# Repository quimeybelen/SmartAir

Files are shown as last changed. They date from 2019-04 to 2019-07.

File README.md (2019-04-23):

# SmartAir

SmartAir es un aire inverter pequeño y transportable controlado desde una aplicación Android desde tu celular.  
Se tendrá la posibilidad de controlar la temperatura interna, la temperatura externa, entre otras funciones más detalladas a continuación.
  
###### Integrantes:  
  - Bedetti, Nicolas (37.844.342) --> nbedetti@gmail.com  
  - Hoz, Aylen (40.129.336)--> ailu.hoz28@gmail.com  
  - Torres, Quimey (38.891.324) --> quimey.torres@gmail.com  

### Materiales a disposición:
	- 5 leds verdes.
	- 5 leds azules.
	- 5 leds blancos.
	- 5 leds rojos.
	- 1 buzzer.
	- 1 sensor de inclinación.
	- 1 protoboard de 400 puntos.
	- Arduino Uno SMD CH340.
	- 1 cable USB.
	- 50 cables M-M.
	- 5 resistencias de 200k.
	- 5 resistencias de 10k.
	- 5 resistencias de 1k.
	- 1 tira de 40 pines.
	- 2 celdas peltier TEC1-12706.
	- 3 sensores de temperatura TMP36.
	- Modulo bluetooth HC-06 slave.
	- Sensor optico infrarrojo reflectivo.
	- Modulo WIFI Esp8266.
	- Fuente de PC de 12V.
	- 2 coolers (con disipador).
	- Disipadores.
	- Pasta térmica.
	
### Entradas:
- Sensor de temperatura TMP36 (Temperatura interna): Este sensor será utilizado para conocer la temperatura interna del aire inverter.
- Sensor de temperatura TMP36 (Temperatura externa): Este sensor será utilizado para conocer la temperatura del aire que sale por el cooler frontal del aire inverter.
- Sensor de inclinación: Este sensor será utilizado para detectar cuando el aire inverter sea movido de su lugar de manera manual. En este caso se procederá a apagar el aire para proteger sus componentes en caso de movimientos bruscos.
  
### Salidas:
- Cooler frontal: Este cooler será utilizado para impulsar el aire con la temperatura deseada y/o indicada por el usuario.
- Cooler trasero: Este cooler será utilizado para controlar la temperatura interna del aire inverter para evitar un sobrecalentamiento de los componentes.
- Led verde: Este led indicará cuando SmartAir este encendido.
- Led azul: Este led indicará cuando SmartAir este en modo "aire frio".
- Led rojo: Este led indicará cuando SmartAir este en modo "aire cálido".
  
##### Microentregas:
- Microentrega 1:
- [x] Integrantes del grupo y idea del proyecto.
  
- Microentrega 2:
- [x] Materiales.
- [ ] Entradas y salidas del proyecto.
- [ ] Hardware que cumple las funciones del proyecto.
- [ ] Bloques que componen el proyecto.
  
- Microentrega 3:
- [ ] Diagrama funcional.
- [ ] Diagrama físico.
- [ ] Esquema del producto final.
  
- Microentrega 4:
- [ ] Diagrama lógico.
  
- Microentrega 5:
- [ ] Diagrama de software.
- [ ] Circuito de conexión.
  
- Microentrega 6:
- [ ] Secuencia de diseño incremental.
  
- Microentrega 7:
- [ ] Explicación del proyecto.
- [ ] Objetivos (Para qué sirve, que problema rsuelve y como lo resuelve).
- [ ] Utilización (Como se opera, que necesita para funcionar, en qué secuencia cumple el objetivo).
- [ ] Como funciona internamente.
- [ ] Procedimiento (Como logra el objetivo).

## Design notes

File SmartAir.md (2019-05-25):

# SmartAir

SmartAir es un aire inverter pequeño y transportable controlado desde una aplicación Android desde tu celular.  
Se tendrá la posibilidad de controlar la temperatura interna, la temperatura externa, entre otras funciones más detalladas a continuación.
  
###### Integrantes:  
  - Bedetti, Nicolas (37.844.342) --> nbedetti@gmail.com  
  - Hoz, Aylen (40.129.336)--> ailu.hoz28@gmail.com  
  - Torres, Quimey (38.891.324) --> quimey.torres@gmail.com  

### Materiales a disposición:
	- 5 leds verdes.
	- 5 leds azules.
	- 5 leds blancos.
	- 5 leds rojos.
	- 1 buzzer.
	- 1 sensor de inclinación.
	- 1 protoboard de 400 puntos.
	- Arduino Uno SMD CH340.
	- 1 cable USB.
	- 50 cables M-M.
	- 5 resistencias de 200k.
	- 5 resistencias de 10k.
	- 5 resistencias de 1k.
	- 1 tira de 40 pines.
	- 2 celdas peltier TEC1-12706.
	- 3 sensores de temperatura TMP36.
	- Modulo bluetooth HC-06 slave.
	- Sensor optico infrarrojo reflectivo.
	- Modulo WIFI Esp8266.
	- Fuente de PC de 12V.
	- 2 coolers (con disipador).
	- Disipadores.
	- Pasta térmica.
	
### Entradas:
- Sensor de temperatura TMP36 (Temperatura interna): Este sensor será utilizado para conocer la temperatura interna del aire inverter.
- Sensor de temperatura TMP36 (Temperatura externa): Este sensor será utilizado para conocer la temperatura del aire que sale por el cooler frontal del aire inverter.
- Sensor de inclinación: Este sensor será utilizado para detectar cuando el aire inverter sea movido de su lugar de manera manual. En este caso se procederá a apagar el aire para proteger sus componentes en caso de movimientos bruscos.
  
### Salidas:
- Cooler frontal: Este cooler será utilizado para impulsar el aire con la temperatura deseada y/o indicada por el usuario.
- Cooler trasero: Este cooler será utilizado para controlar la temperatura interna del aire inverter para evitar un sobrecalentamiento de los componentes.
- Led verde: Este led indicará cuando SmartAir este encendido.
- Led azul: Este led indicará cuando SmartAir este en modo "aire frio".
- Led rojo: Este led indicará cuando SmartAir este en modo "aire cálido".
- Celdas peltier: Estas se encenderán y apagarán para controlar la temperatura, tambien se cambiará la polaridad para entregar frío o calor según el modo en el que funcione el aire.
- Buzzer: Se utiliza para indicar de forma sonora el encendido, apagado, cambio de modo, al subir o bajar la temperatura y velocidad de los coolers, ademas para indicar que el dispositivo se encuentra en modo seguridad.
  
##### Microentregas:
- Microentrega 1:
- [x] Integrantes del grupo y idea del proyecto.
  
- Microentrega 2:
- [x] Materiales.
- [x] Entradas y salidas del proyecto.
- [x] Hardware que cumple las funciones del proyecto.
- [x] Bloques que componen el proyecto.
  
- Microentrega 3:
- [x] Diagrama funcional.
- [x] Diagrama físico.
- [x] Esquema del producto final.
  
- Microentrega 4:
- [x] Diagrama lógico.
  
- Microentrega 5:
- [x] Diagrama de software.
- [ ] Circuito de conexión.
  
- Microentrega 6:
- [x] Secuencia de diseño incremental.
  
- Microentrega 7:
- [x] Explicación del proyecto.
- [x] Objetivos (Para qué sirve, que problema rsuelve y como lo resuelve).
- [x] Utilización (Como se opera, que necesita para funcionar, en qué secuencia cumple el objetivo).
- [ ] Como funciona internamente.
- [ ] Procedimiento (Como logra el objetivo).

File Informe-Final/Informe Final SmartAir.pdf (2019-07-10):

Sistemas Operativos Avanzados - UNLaM

# Informe Final

SmartAir

### Integrantes: Bedetti, Nicolas 37.844.342 nbedetti@gmail.com Hoz, Aylen 40.129.336 ailu.hoz28@gmail.com Torres, Quimey 38.891.324 quimey.torres@gmail.com

Página 1 de 34

## Índice

Página 2 de 34

Página 3 de 34

# Smart Air

### Objetivo

Desarrollar un Sistema embebido (Smart Air) aplicando los conocimientos adquiridos durante el cuatrimestre. SmartAir es un aire inverter pequeño y transportable controlado desde una aplicación Android desde tu celular.

Se tendrá la posibilidad de controlar la temperatura interna, la temperatura externa, entre otras funciones más detalladas a continuación.

### Descripción general del sistema – Manual de Uso

Smart Air es un producto diseñado especialmente para poder ser utilizado en cualquier lugar donde puede enchufarse, es perfecto para refrescarse en un día de verano o para calentarse en un día frío de invierno, gracias a que es un aire inverter. Brinda la posibilidad de prender y apagar el aparato, entre otras funciones, a través de una aplicación Android utilizando Bluetooth.

El sistema embebido (SE) tomará la temperatura exterior de la habitación en la que es colocado y la temperatura interna por donde el aire (cálido o frío) es expulsado. De esta forma al seleccionar en la aplicación el modo elegido, sea frío, calor, ventilación (solo aire sin refrigeración o calor) o automático (24°C). Se encenderán en el modo correcto las placas Peltier que tiene internamente para generar frío, calor o esta apagadas según corresponda.

Además, se podrá elegir desde la aplicación con qué velocidad queremos que el aire sea expulsado en caso de requerir enfriar o calentar la habitación más rápido.

Para un mejor uso es recomendable que la parte trasera del dispositivo donde se elimina el aire se apunte al exterior, al igual que los aires convencionales.

El dispositivo también cuenta con un sensor de inclinación el cual permite, cuando el dispositivo está encendido y es transportado, que este se apague para no generar daños internos.

Por último, cuenta con un buzzer que indica cuando el dispositivo se enciende, apaga, cambia de temperatura, velocidad y modo, además de tres leds frontales que indican el estado del dispositivo:

- Al encender el dispositivo se prenderá el led verde.
- Al estar en “modo frío”, además de mantener el led verde de encendido, se prenderá el led azul.
- Al estar en “modo calor”, además de mantener el led verde de encendido, se prenderá el led rojo.

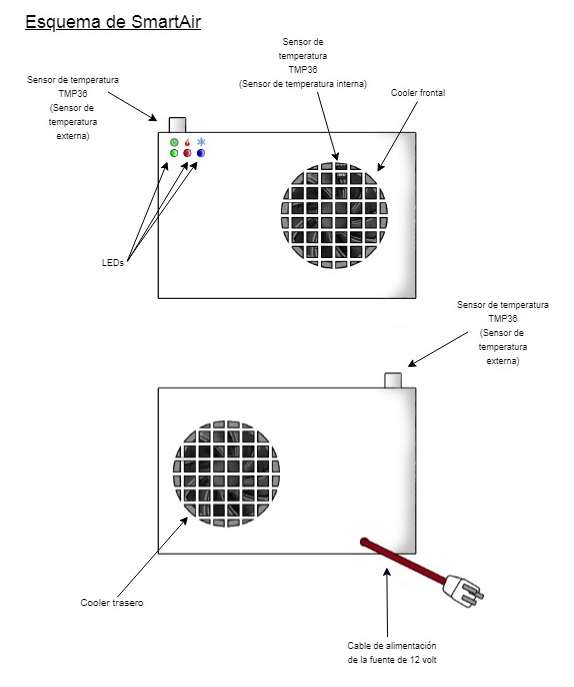
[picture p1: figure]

Página 4 de 34

- Al estar en “modo automático”, además de mantener el led verde de encendido, se prenderán los led azul y rojo.
- Al estar en “modo ventilación”, solo se encuentra encendido el led verde, con solo los ventiladores encendido, sin las peltier.
- Por último, el dispositivo cuando con un “modo seguro”, este se activa cuando el sensor de inclinación detecta que el dispositivo se encuentra en una posición que compromete su integridad, cuando esto sucede se apagarán los led azul y rojo (según corresponda), el buzzer producirá un pitido constante y se apagarán las placas Peltier al igual que los ventiladores internos.

En la siguiente imagen se puede apreciar el dispositivo y como debe ser conectado:

Página 5 de 34

### Componentes

Hardware:
- 1 Placa Arduino UNO SMD CH340.
- 1 Cable USB
- Protoboard de 400 puntos.
- 1 Fuente de computadora 12v.
- Cables macho-macho.
- Cables macho-hembra.
- Pines.
- Modulo Bluetooth HC-05.
- Resistencias 4k7.
- Resistencias 33K.
- Transistores BC337.
- 2 Transistores IRF 540.
- 2 Transistores BC558.
- 2 Transistores BC548.
- Sensores
o 1 Sensor de temperatura TMP-36. o 1 Sensor de temperatura LM-35 o 1 Sensor de inclinación.
- Actuadores
o 1 Buzzer.
o 1 Led Verde.
o 1 Led Rojo.
o 1 Led Azul.
o 2 Celdas Peltier TEC1-12706.
o 2 Coolers con disipador de 8x8cm.

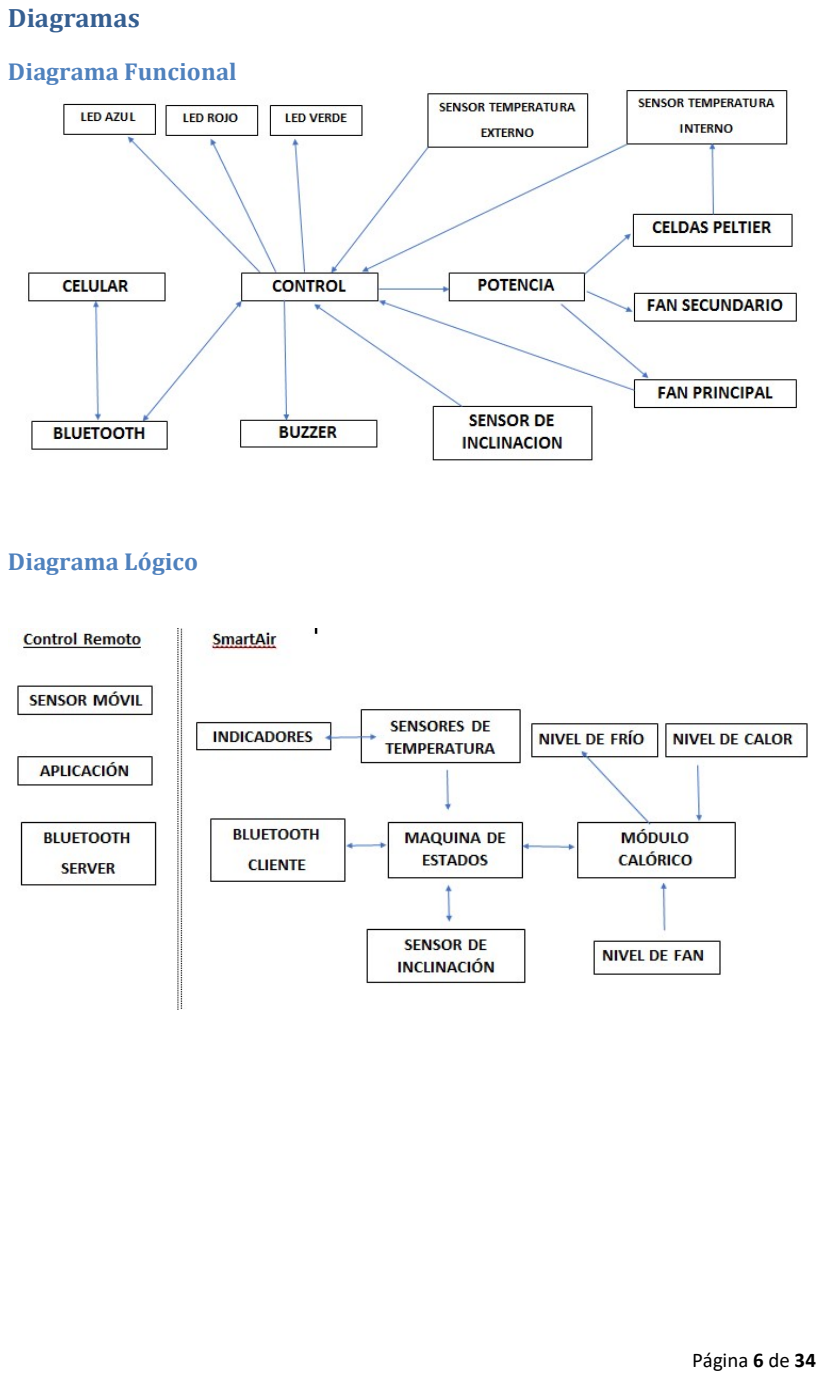
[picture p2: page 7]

Página 6 de 34

### Diagramas

Diagrama Funcional

Diagrama Lógico

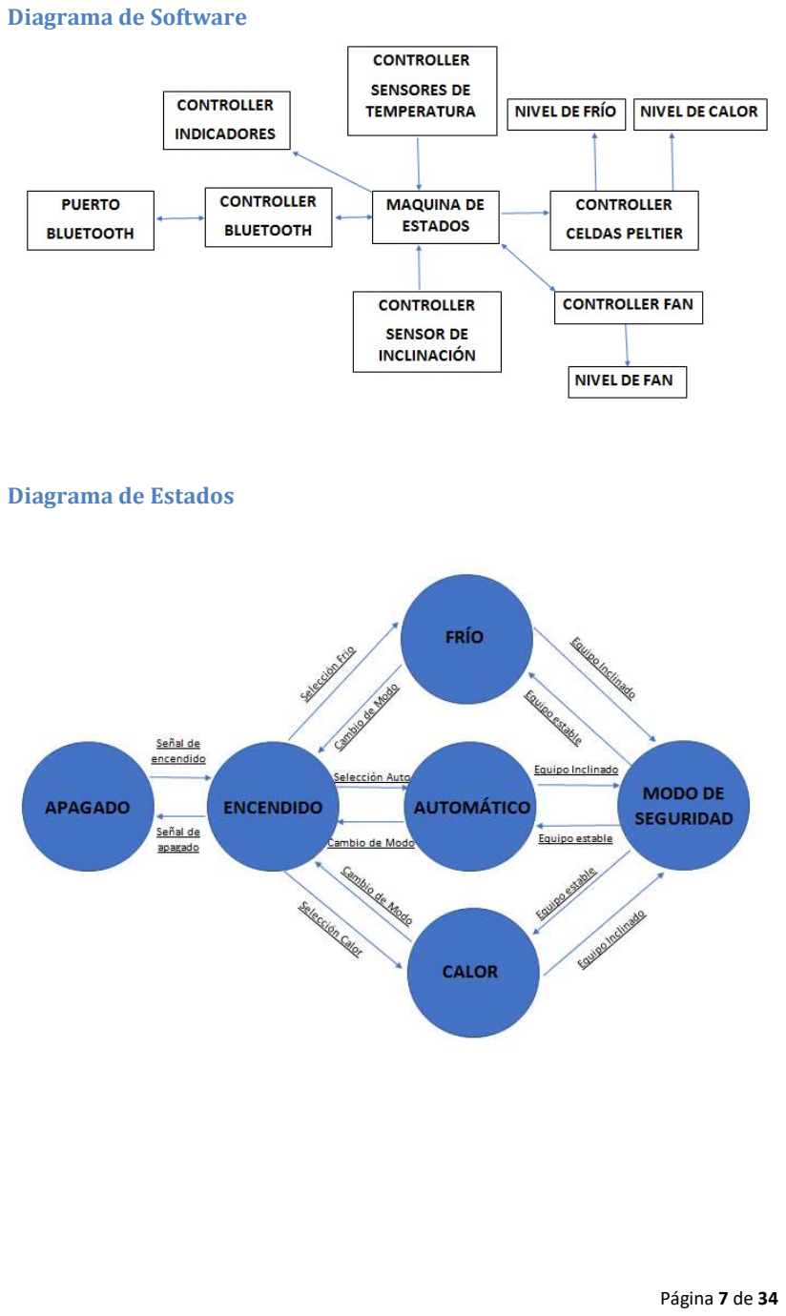
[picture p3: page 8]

Página 7 de 34

Diagrama de Software

Diagrama de Estados

Página 8 de 34

### Implementación del Embebido

Implementación Leds
Pin 4: Led verde (encendido)

Pin 12: Led Azul (modo frío)

Pin 13: Led Rojo (modo calor)

Implementación de Sensor de inclinación
Pin 2: Sensor de inclinación o tilt switch

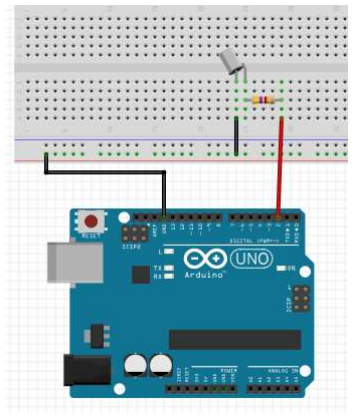
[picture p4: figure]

Página 9 de 34

Implementación de Buzzer
Pin 3 (PWM): Buzzer (se conectó directo)

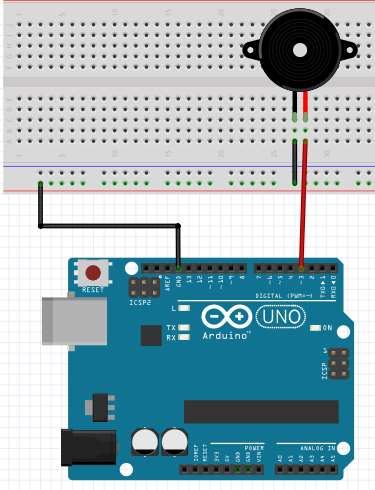
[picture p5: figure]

Implementación de sensores de temperatura
Pin Analógico 0: Sensor de temperatura TMP36 (temperatura interna)

Pin Analógico 1: Sensor de temperatura LM35 (temperatura externa)

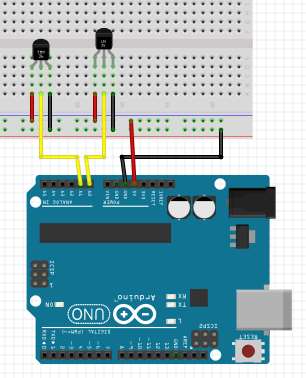
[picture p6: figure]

Página 10 de 34

Implementación de Cooler Frontal
Pin 5 (PWM): control de velocidad del cooler conectando cable de alimentación del cooler a transistor BC337.

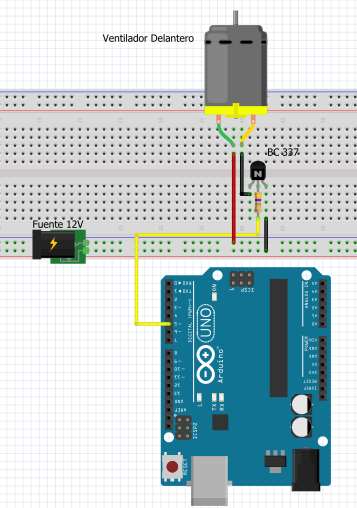
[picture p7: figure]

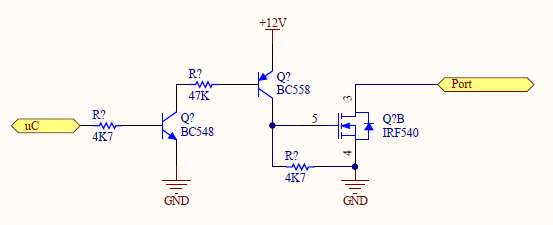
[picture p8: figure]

Página 11 de 34

Implementación de Celdas Peltier:
Las celdas se conectarán cumpliendo con el siguiente circuito, repitiéndolo para cada una:

Pin 6: Peltier para calor.

Pin 7: Peltier para frio.

Implementación módulo Bluetooth HC-05

5V: Vcc

Pin 10 (PWM): TXD

Pin 11 (PWM): RXD

GND: GND

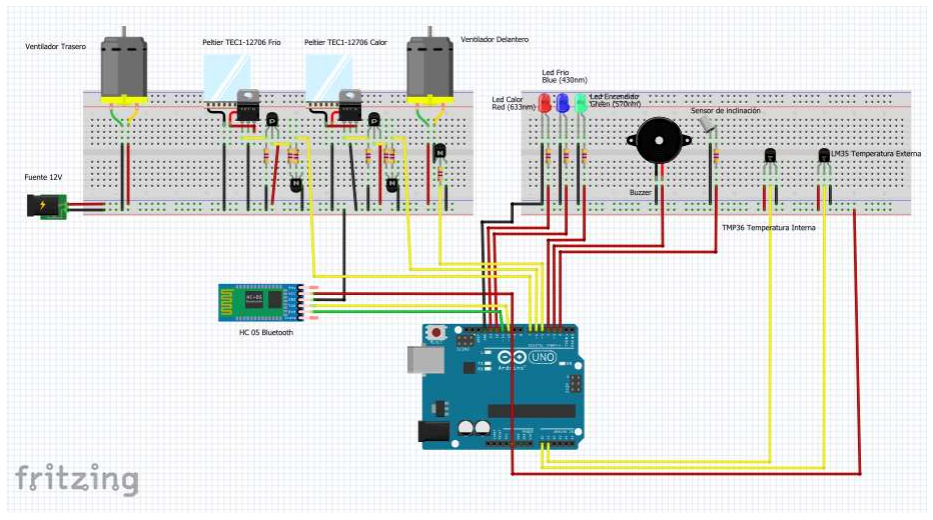
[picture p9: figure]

Página 12 de 34

### Circuito Completo

Como se puede apreciar en la figura, se decidió utilizar dos placas una para los componentes que va a estar mas a la vista como los leds, buzzer y sensores que son componentes delicados y pequeños. Y otra, para los componentes internos y más pesados como el ventilador frontal y las placas peltier. Decidimos no manejar el ventilador trasero y que se encuentra prendido constantemente desde que se conecta el dispositivo debido a que es necesario expulsar el aire desde adentro del dispositivo en todo momento.

Página 13 de 34

### Descripción de los componentes

Arduino Uno:

Arduino es una plataforma de prototipos electrónica de código abierto (open-source) basada en hardware y software flexibles y fáciles de usar. Arduino puede sentir el entorno mediante la recepción de entradas desde una variedad de sensores y puede afectar a su alrededor mediante el control de luces, motores y otros artefactos. El microcontrolador de la placa se programa usando el Arduino Programming Language (basado en Wiring).

La mayor parte de los Arduinos funcionan a 5V, como es el caso del Arduino Uno. Todos tienen un regulador de tensión, que básicamente es un componente que convierte el voltaje que con el que alimentamos la placa (lo recomendado es entre 7 y 12V) a 5V, desechando lo restante.

Este regulador necesita un voltaje mínimo para para proporcionar 5V que está entorno 6.5-7V, pero todo lo que esté por encima de ese valor se desperdicia.

Página 14 de 34

Módulo Bluetooth HC-05

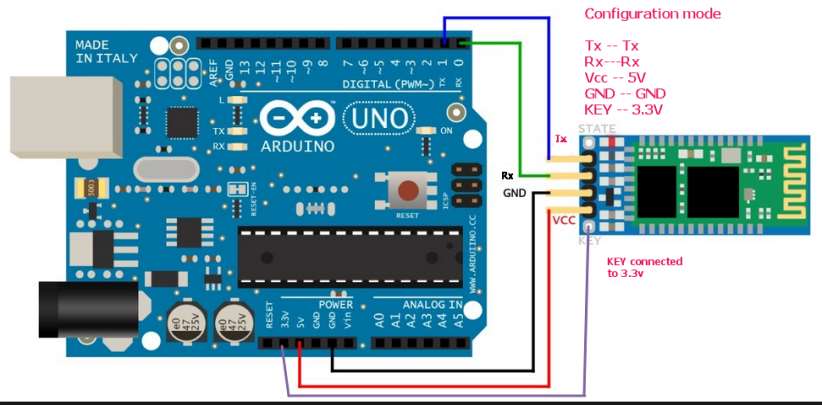
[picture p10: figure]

Estos módulos vienen maestro y esclavo en una misma placa y vía comandos AT se configura cuál de los dos modos queremos usar. Por defecto viene en modo Esclavo.

El chip en si trabaja en 3.3 V, pero viene soldado sobre una placa que adapta todos sus pines para poder usarlo en 5V y así sea 100% compatible con Arduino.

La velocidad por defecto es de 9600 baudios.

Tiene un alcance de 18 metros.

Modulo bluetooth hc-05 como esclavo: Cuando está configurado de esta forma, se comporta similar a un HC-06, espera que un dispositivo bluetooth maestro se conecte a este, generalmente se utiliza cuando se necesita comunicarse con una PC o Celular, pues estos se comportan como dispositivos maestros.

Modulo bluetooth hc-05 como Maestro: En este modo, EL HC-05 es el que inicia la conexión. Un dispositivo maestro solo se puede conectarse con un dispositivo esclavo. Generalmente se utiliza este modo para comunicarse entre módulos bluetooth. Es necesario antes especificar con qué dispositivo se tiene que comunicar. Mediante el pin TX, Arduino enviará datos, y mediante el RX, recibirá datos.

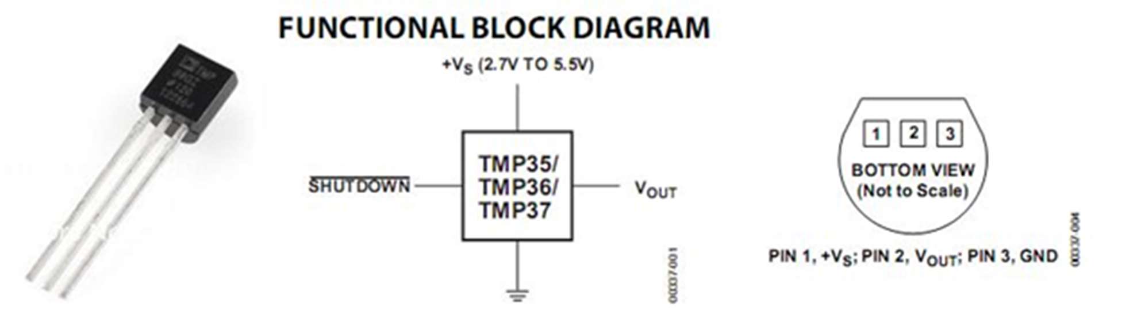
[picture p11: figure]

Página 15 de 34

Sensor de Temperatura TMP-36
El sensor de temperatura TMP36 es un sensor analógico que permite realizar medidas de temperatura bastante precisas.

El sensor empleado es de tipo TO-92 (encapsulado como el DS18B20 o el de algunos transistores). Además, se caracteriza por ser un sensor que es muy empleado para realizar medidas de temperatura y es muy sencillo de emplear (no hacen falta librerías para su uso). Es un sensor que se puede alimentar entre un rango de voltaje que va desde los 2.7V hasta los 5.5V, viene calibrado directamente en grados centígrados (ºC), presenta un factor de escala lineal de 10 mV/ºC (esto es la relación entre el cambio en la señal de salida y el cambio en la señal de la medida, es decir, cada 10 mV aumenta 1 ºC). Las características generales son:

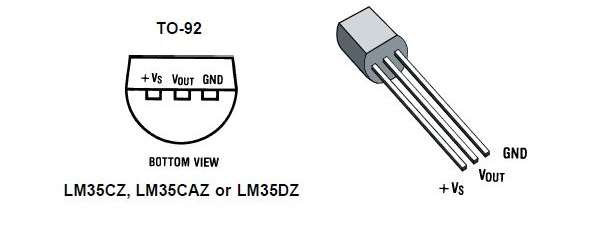
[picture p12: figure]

Página 16 de 34

Sensor de temperatura LM-35

El LM35 es un sensor de temperatura con una precisión calibrada de 1 °C. Su rango de medición abarca desde -55 °C hasta 150 °C. La salida es lineal y cada grado Celsius equivale a

### 10 mV, por lo tanto:

- 150 °C = 1500 mV
- -55 °C = -550 mV1
- Opera de 4v a 30v.
- Está calibrado directamente en grados Celsius.
- La tensión de salida es proporcional a la temperatura.
- Tiene una precisión garantizada de 0.5 °C a 25 °C.
- Baja impedancia de salida.
- Baja corriente de alimentación (60 μA).

El LM35 no requiere de circuitos adicionales para calibrarlo externamente. La baja impedancia de salida, su salida lineal y su precisa calibración hace posible que este integrado sea instalado fácilmente en un circuito de control. Debido a su baja corriente de alimentación se produce un efecto de auto calentamiento muy reducido. Se encuentra en diferentes tipos de encapsulado, el más común es el TO-92, utilizado por transistores de baja potencia.

El TO-92 es el encapsulado más utilizado en la construcción de transistores. El encapsulado está usualmente hecho de epoxy o plástico, y presenta un tamaño bien

Página 17 de 34

Sensor de Inclinación

Son sensores de unos pocos milímetros de longitud, que llevan en su interior una o dos pequeñas bolas conductoras, capaces de cerrar el circuito con los pines metálicos inferiores del cilindro.

Cuando hacen contacto permiten el paso de la corriente y

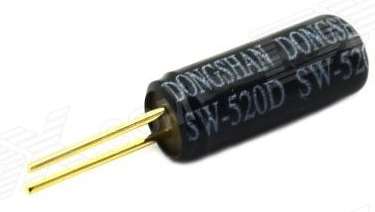
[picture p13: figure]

cierran el contacto exactamente igual que si fueran un interruptor (Y de hecho se manejan igual) pero que a partir de un cierto Angulo de inclinación dejan de hacer contacto y abren el contacto.

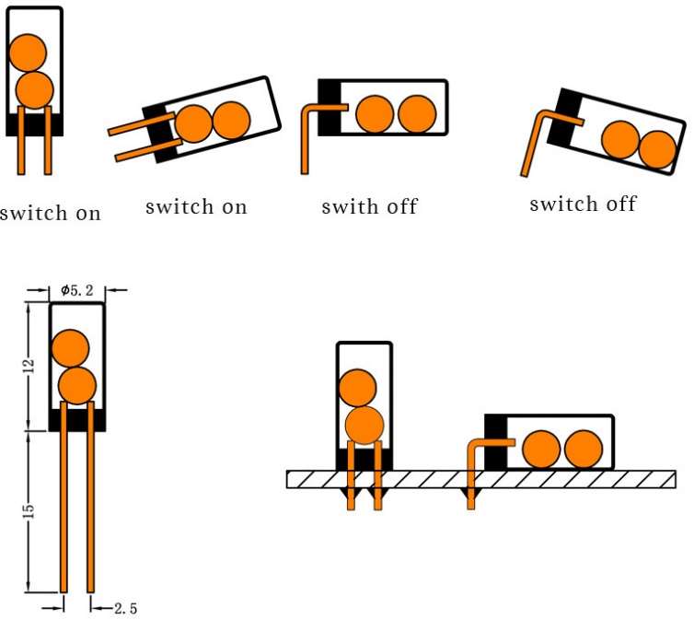
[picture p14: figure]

LED
Un diodo emisor de luz o led (light-emitting diode) es una fuente de luz constituida por un material semiconductor dotado de dos terminales. Se trata de un diodo de unión p-n, que emite luz cuando está activado. Si se aplica una tensión adecuada a los terminales, los electrones se recombinan con los huecos en la región de la unión p-n del dispositivo, liberando energía en forma de fotones. Este efecto se denomina electroluminiscencia, y el color de la luz generada (que depende de la energía de los fotones emitidos) viene determinado por la anchura de la banda prohibida del semiconductor. Los ledes son normalmente

pequeños (menos de 1 mm) y se les asocian algunas componentes ópticas para configurar un patrón de radiación.

Página 18 de 34

Buzzer

Es un transductor electroacústico que produce un sonido o zumbido continuo o intermitente de un mismo tono (generalmente agudo). Sirve como mecanismo de señalización o aviso y se utiliza en múltiples sistemas, como en automóviles o en electrodomésticos, incluidos los despertadores.

Inicialmente este dispositivo estaba basado en un sistema

electromecánico que era similar a una campana eléctrica, pero sin el badajo metálico, el cual imitaba el sonido de una campana.

Su construcción consta de dos elementos, un electroimán o disco piezoeléctrico y una lámina metálica de acero. El buzzer puede ser conectado a circuitos integrados especiales para así lograr distintos tonos.

Cuando se acciona, la corriente pasa por la bobina del electroimán y produce un campo magnético variable que hace vibrar la lámina de acero sobre la armadura, o bien, la corriente pasa por el disco piezoeléctrico haciéndolo entrar en resonancia eléctrica y produciendo ultrasonidos que son amplificados por la lámina de acero.
Celda Peltier TEC1-12706
Especificaciones:
- Material cerámico
- Cable de 30cm
- Temperatura lado caliente: 50-57ºC
- Delta de temperatura: 66-75ºC
- Corriente máxima: 6.4A
- Voltaje nominal: 12V
- Voltaje máximo: 16.4V
- Potencia nominal: 72W
- Resistencia de la celda 1.98-2.30 Ohms

Se utiliza para enfriar o calentar un objeto, ideal para experimentos o controles de temperatura, si se utiliza por largos periodos de tiempo se recomienda utilizar un disipador en la zona caliente, además de recubrir la zona con pasta termina para una mejor termo conducción de los materiales. La celda se controla con 12V, pero puedes utilizarla con un rango de voltaje de los 3 a los 16V. Dado que la celda consume una cantidad considerable de corriente tienes que tomar en cuenta que tu fuente tenga la corriente necesaria, si no, no va a funcionar con su máxima eficiencia.

Una celda peltier contiene un arreglo de paletas de semiconductor de material Bismuto Telurio que se encuentran dopadas con un tipo de portador positivo o negativo. Los pares de portadores se configuran para estar conectados en serie eléctricamente y en paralelo

Página 19 de 34

térmicamente hablando. Cuando un voltaje de corriente directa se aplica al módulo, las cargas positivas y negativas de los portadores absorben energía de un sustrato y la transfiere al sustrato del lado opuesto. La superficie que absorbe la energía caliente se enfría y la superficie donde la energía calorífica se desprende, se calienta. Si se polariza la celda peltier al inverso, el proceso enfría la cara opuesta.

Cuando una celda peltier se polariza, la cara o lado fría absorbe "calor" y la cara que pierde energía emite calor. La diferencia entre ambas caras hará que al final la celda se caliente más de lo que se enfría. Por lo tanto, para montar una celda peltier se requiere tener un disipador. De preferencia este disipador debería de ser de Aluminio el cual es más eficiente para dispersar la temperatura extra. Cuando una celda peltier se encuentra montada a un radiador se tiene una unidad de enfriado.

Página 20 de 34

### Aplicación Android

Composición de la aplicación
La aplicación Android del embebido SmartAir se encuentra compuesta por:
- 11 activities con sus respectivos archivos XML:
- MainActivity: Representa la pantalla de inicio de la aplicación donde puede elegirse el modo en el que se encontrará SmartAir.
- ModoFrioActivity: Representa la pantalla de ‘modo frio’ de la aplicación cuando SmartAir se encuentra en su modo frio.
- ModoCalorActivity: Representa la pantalla de ‘modo calor’ de la aplicación cuando SmartAir se encuentra en su modo ‘calefacción’.
- ModoAutomaticoActivity: Representa la pantalla de ‘modo automático’ de la aplicación cuando SmartAir se encuentra en su modo automático, es decir que la temperatura ideal será elegida por SmartAir, siendo esta de 24 °C.
- ModoVentilacionActivity: Representa la pantalla de ‘modo ventilación’ de la aplicación cuando SmartAir se encuentra en su modo ventilación donde únicamente se encuentra encendido el ventilador.
- ModoSeguroActivity: Representa la pantalla de ‘modo seguro’ de la aplicación cuando SmartAir se encuentra siendo transportado de manera brusca, por lo que sus componentes se encuentran en peligro.
- ErrorConexionMainActivity: Representa el mensaje de error de la aplicación que aparece cuando nos encontramos en la pantalla de inicio y se intenta comunicar con SmartAir, siendo la comunicación rechazada debido a que el mismo no se encuentra conectado.
- ErrorConexionFrioActivity: Representa el mensaje de error de la aplicación que aparece cuando nos encontramos en la pantalla de ‘modo frio’ y se intenta comunicar con SmartAir, siendo la comunicación rechazada debido a que el mismo no se encuentra conectado.
- ErrorConexionCalorActivity: Representa el mensaje de error de la aplicación que aparece cuando nos encontramos en la pantalla de ‘modo calor’ y se intenta comunicar con SmartAir, siendo la comunicación rechazada debido a que el mismo no se encuentra conectado.
- ErrorConexionAutomaticoActivity: Representa el mensaje de error de la aplicación que aparece cuando nos encontramos en la pantalla de ‘modo automático’ y se intenta comunicar con SmartAir, siendo la comunicación rechazada debido a que el mismo no se encuentra conectado.
- ErrorConexionVentilacionActivity: Representa el mensaje de error de la aplicación que aparece cuando nos encontramos en la pantalla de ‘modo ventilación’ y se intenta comunicar con SmartAir, siendo la comunicación rechazada debido a que el mismo no se encuentra conectado.
- 2 servicios:
- ConexionBluetoothService: Nos provee el servicio de comunicación vía bluetooth entre la aplicación de Android y SmartAir, tanto para el envío de mensajes de la aplicación al SmartAir y viceversa.

Página 21 de 34

- SensoresService: Nos provee el servicio de los sensores de proximidad, luz y el shake, detectando los cambios que ocurren en los mismos y realizando, a partir de estos cambios detectados, acciones específicas.
- Sensor de proximidad: Cuando el sensor detecte que el dispositivo móvil se encuentra muy próximo a un objeto y la aplicación se encuentra abierta, bloqueara todos los botones de la pantalla en la cual se encuentre la aplicación.
- Sensor de luz: Cuando el sensor de luz detecte que en el ambiente donde se encuentra el dispositivo móvil tiene una luz muy tenue y no se detectan cambios en el sensor de proximidad, indicara a SmartAir que deberá cambiarse a modo automático. Si el usuario no desea que SmartAir se encuentre en dicho modo, podrá optar por cambiarlo.
- Shake: Cuando el dispositivo móvil detecte un shake, indicara al SmartAir que debe prenderse u apagarse dependiendo en qué modo este al momento de ocurrido el shake.

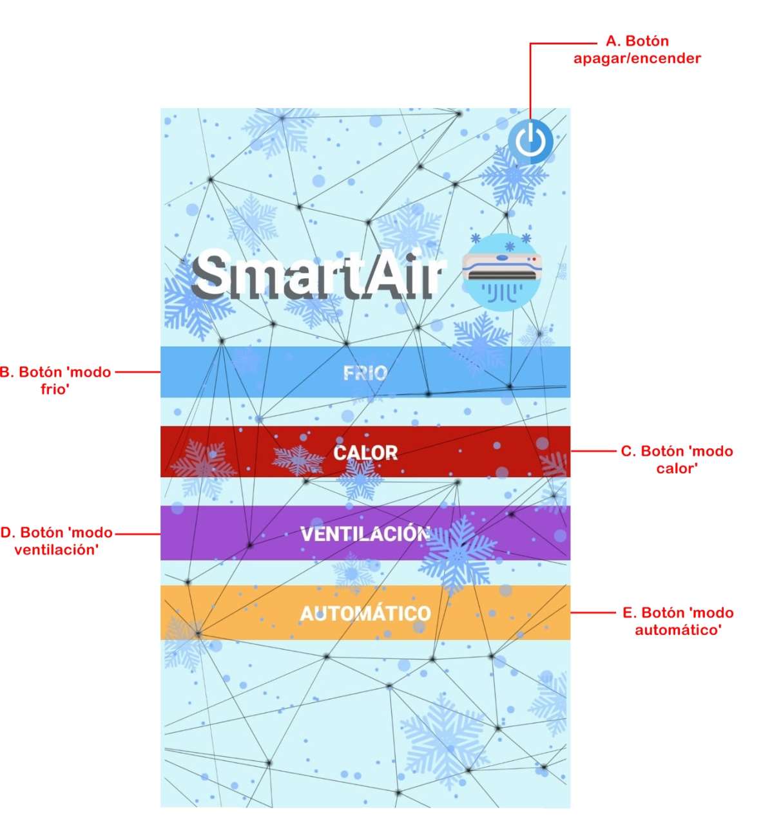
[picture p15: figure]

Página 22 de 34

Pantallas de la aplicación

- MainActivity:
A. Botón apagar/encender: Al presionar dicho botón se encenderá u apagará SmartAir dependiendo el estado en el que el mismo se encontraba cuando el botón fue seleccionado. En caso de que SmartAir se encuentre apagado, la pantalla tendrá sus botones deshabilitado como se observa en la figura.
B. Botón ‘modo frio’: Al seleccionar dicho botón indicaremos a SmartAir que deseamos el modo frio y la aplicación mostrara la pantalla de control del modo correspondiente.
C. Botón ‘modo calor’: Al seleccionar dicho botón indicaremos a SmartAir que deseamos el modo calor y la aplicación mostrara la pantalla de control del modo correspondiente.
D. Botón ‘modo ventilación’: Al seleccionar dicho botón indicaremos a SmartAir que deseamos el modo ventilación y la aplicación mostrara la pantalla de control del modo correspondiente.
E. Botón ‘modo automático’: Al seleccionar dicho botón indicaremos a SmartAir que deseamos el modo automático y la aplicación mostrara la pantalla de control del modo correspondiente.

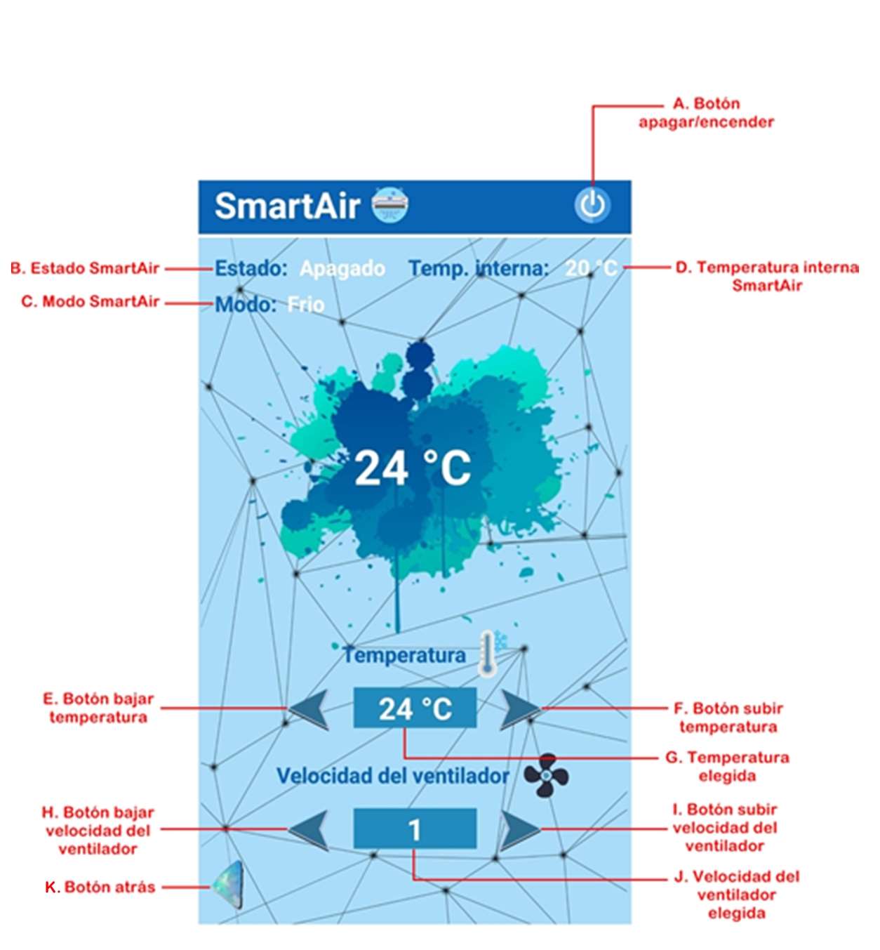
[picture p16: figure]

Página 23 de 34

- ModoFrioActivity:
A. Botón apagar/encender: Al presionar dicho botón se encenderá u apagará SmartAir dependiendo el estado en el que el mismo se encontraba cuando el botón fue seleccionado. En caso de apagar SmartAir, la aplicación volverá a la pantalla de inicio.
B. Estado SmartAir: Nos indica si SmartAir se encuentra prendido u apagado.
C. Modo SmartAir: Nos indica que SmartAir se encuentra en ‘modo frio’.
D. Temperatura interna SmartAir: Nos indica la temperatura que posee internamente SmartAir.
E. Botón bajar temperatura: Al seleccionar dicho botón disminuimos en uno el valor de la temperatura elegida.

Página 24 de 34

F. Botón subir temperatura: Al seleccionar dicho botón aumentamos en uno el valor de la temperatura elegida.
G. Temperatura elegida: Indica la temperatura seleccionada por el usuario de la aplicación. Puede ser modificada con los botones de bajar temperatura y subir temperatura, pero dicho valor nunca podrá ser menor que 18 °C, mayor a 26 °C, ni mayor a la temperatura externa plasmada en la mancha de tinta de la pantalla.
H. Botón bajar velocidad del ventilador: Al seleccionar dicho botón disminuimos en uno el valor de la velocidad del ventilador elegida.
I. Botón subir velocidad del ventilador: Al seleccionar dicho botón aumentamos en uno el valor de la velocidad del ventilador elegida.
J. Velocidad del ventilador elegida: Indica la velocidad del ventilador seleccionada por el usuario de la aplicación. Puede ser modificada con los botones de bajar velocidad del ventilador y subir velocidad del ventilador, pero dicho valor nunca podrá ser menor que 1 ni mayor a 5.
K. Botón atrás: Al seleccionar dicho botón volveremos a la pantalla de inicio, lo cual nos permitirá seleccionar otro modo deseado.

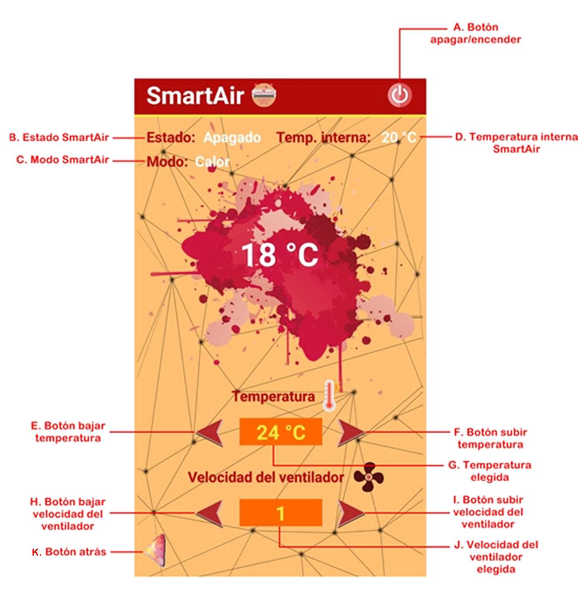
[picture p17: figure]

Página 25 de 34

- ModoCalorActivity:
A. Botón apagar/encender: Al presionar dicho botón se encenderá u apagará SmartAir dependiendo el estado en el que el mismo se encontraba cuando el botón fue seleccionado. En caso de apagar SmartAir, la aplicación volverá a la pantalla de inicio.
B. Estado SmartAir: Nos indica si SmartAir se encuentra prendido u apagado.
C. Modo SmartAir: Nos indica que SmartAir se encuentra en ‘modo calor’.
D. Temperatura interna SmartAir: Nos indica la temperatura que posee internamente SmartAir.
E. Botón bajar temperatura: Al seleccionar dicho botón disminuimos en uno el valor de la temperatura elegida.
F. Botón subir temperatura: Al seleccionar dicho botón aumentamos en uno el valor de la temperatura elegida.
G. Temperatura elegida: Indica la temperatura seleccionada por el usuario de la aplicación. Puede ser modificada con los botones de bajar temperatura y subir temperatura, pero dicho

Página 26 de 34

valor nunca podrá ser menor que 18 °C, mayor a 26 °C, ni menor a la temperatura externa plasmada en la mancha de tinta de la pantalla.

H. Botón bajar velocidad del ventilador: Al seleccionar dicho botón disminuimos en uno el valor de la velocidad del ventilador elegida.
I. Botón subir velocidad del ventilador: Al seleccionar dicho botón aumentamos en uno el valor de la velocidad del ventilador elegida.
J. Velocidad del ventilador elegida: Indica la velocidad del ventilador seleccionada por el usuario de la aplicación. Puede ser modificada con los botones de bajar velocidad del ventilador y subir velocidad del ventilador, pero dicho valor nunca podrá ser menor que 1 ni mayor a 5.
K. Botón atrás: Al seleccionar dicho botón volveremos a la pantalla de inicio, lo cual nos permitirá seleccionar otro modo deseado.

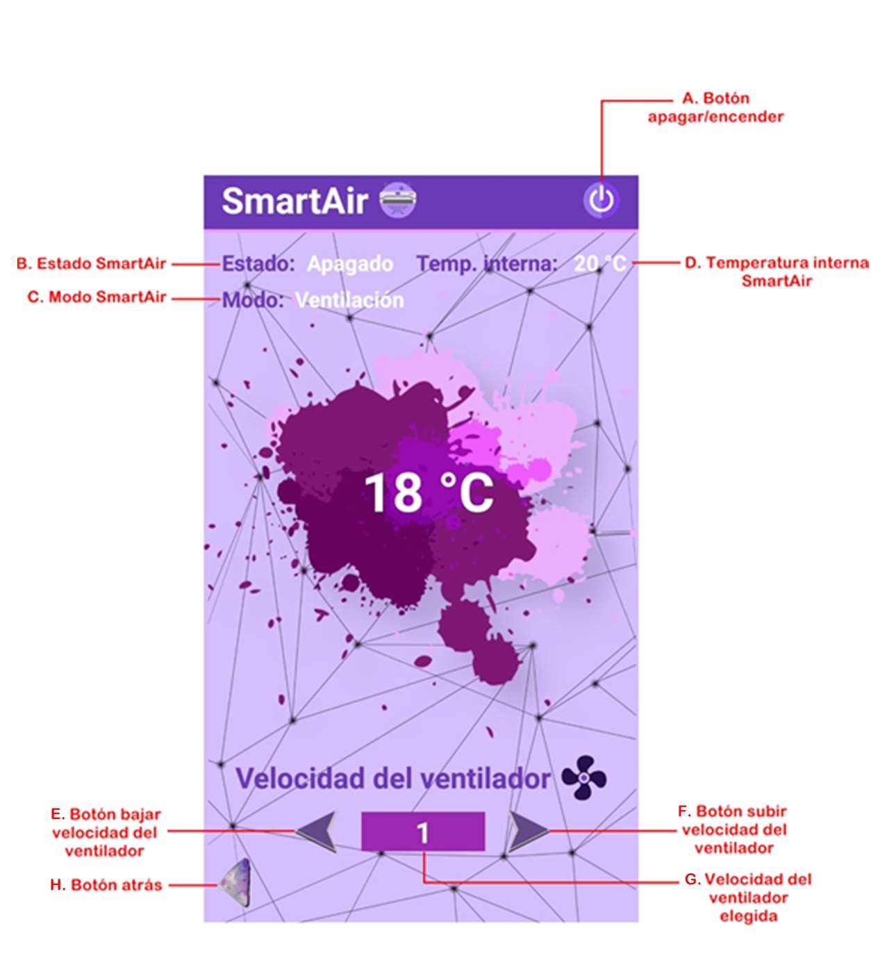
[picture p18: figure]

Página 27 de 34

-ModoVentilacionActivity:

A. Botón apagar/encender: Al presionar dicho botón se encenderá u apagará SmartAir dependiendo el estado en el que el mismo se encontraba cuando el botón fue seleccionado. En caso de apagar SmartAir, la aplicación volverá a la pantalla de inicio.
B. Estado SmartAir: Nos indica si SmartAir se encuentra prendido u apagado.
C. Modo SmartAir: Nos indica que SmartAir se encuentra en ‘modo ventilación’.
D. Temperatura interna SmartAir: Nos indica la temperatura que posee internamente SmartAir.
E. Botón bajar velocidad del ventilador: Al seleccionar dicho botón disminuimos en uno el valor de la velocidad del ventilador elegida.

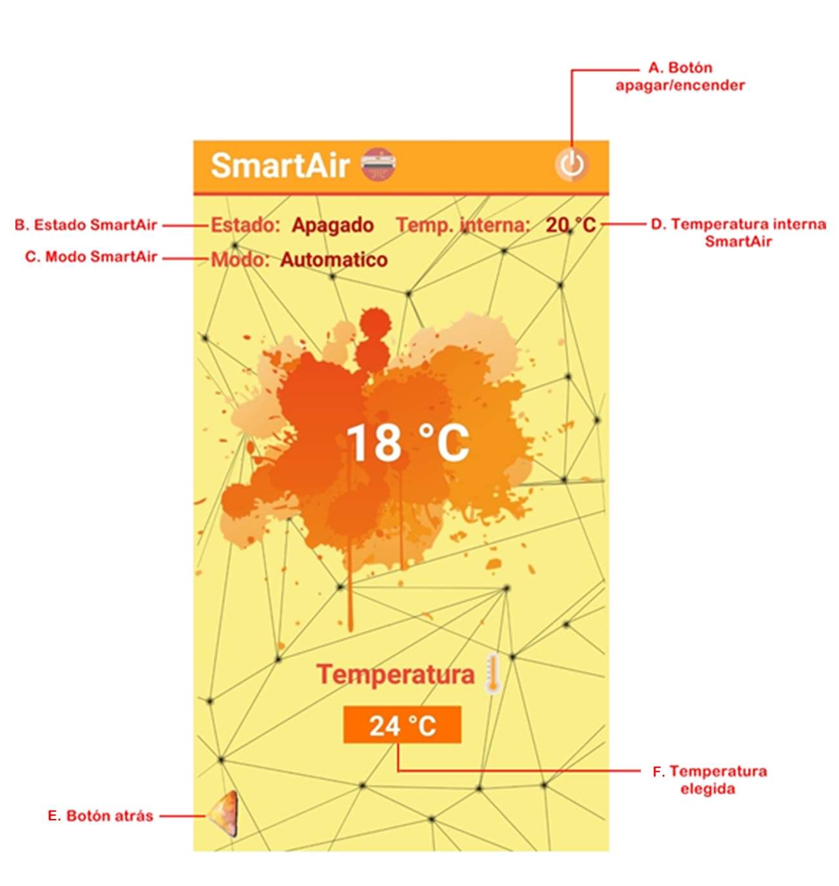
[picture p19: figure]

Página 28 de 34

F. Botón subir velocidad del ventilador: Al seleccionar dicho botón aumentamos en uno el valor de la velocidad del ventilador elegida.
G. Velocidad del ventilador elegida: Indica la velocidad del ventilador seleccionada por el usuario de la aplicación. Puede ser modificada con los botones de bajar velocidad del ventilador y subir velocidad del ventilador, pero dicho valor nunca podrá ser menor que 1 ni mayor a 5.
H. Botón atrás: Al seleccionar dicho botón volveremos a la pantalla de inicio, lo cual nos permitirá seleccionar otro modo deseado.

-ModoAutomaticoActivity:

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

Página 29 de 34

C. Modo SmartAir: Nos indica que SmartAir se encuentra en ‘modo frio’.
D. Temperatura interna SmartAir: Nos indica la temperatura que posee internamente SmartAir.
E. Temperatura elegida: Indica la temperatura seleccionada, la cual en este modo resulta ser siempre de 24 °C.
F. Botón atrás: Al seleccionar dicho botón volveremos a la pantalla de inicio, lo cual nos permitirá seleccionar otro modo deseado.

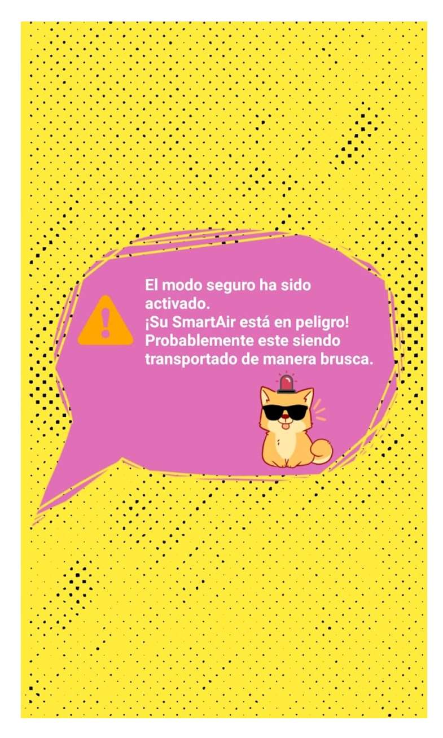
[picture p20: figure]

- ModoSeguroActivity:

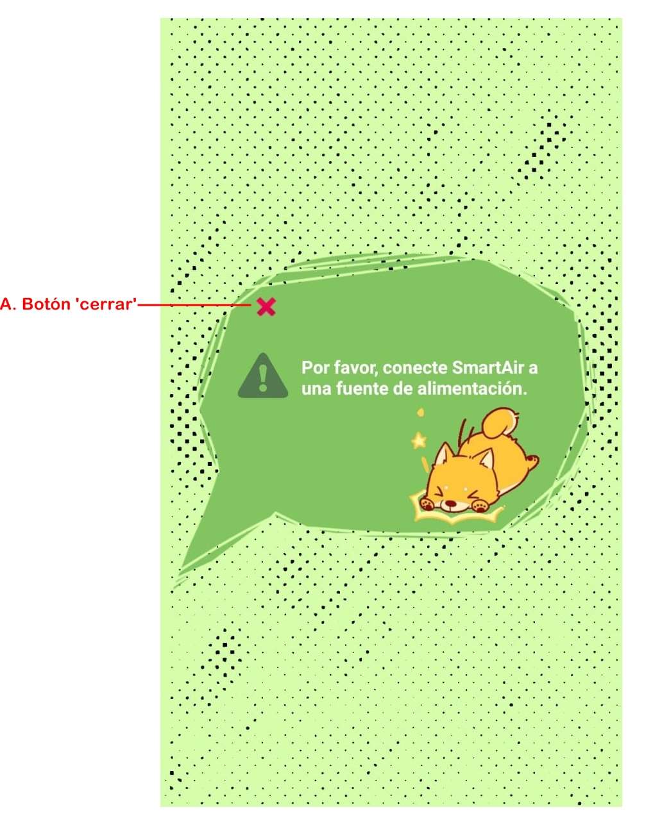
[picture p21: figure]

Página 30 de 34

- ErrorConexionMainActivity:
A. Botón ‘cerrar’: Al seleccionar dicho botón cerraremos el mensaje de error que surge cuando existe una falla de conexión con SmartAir mientras se está en la pantalla de inicio.

Página 31 de 34

- ErrorConexionFrioActivity:
A. Botón ‘cerrar’: Al seleccionar dicho botón cerraremos el mensaje de error que surge cuando existe una falla de conexión con SmartAir mientras se está en ‘modo frio’.

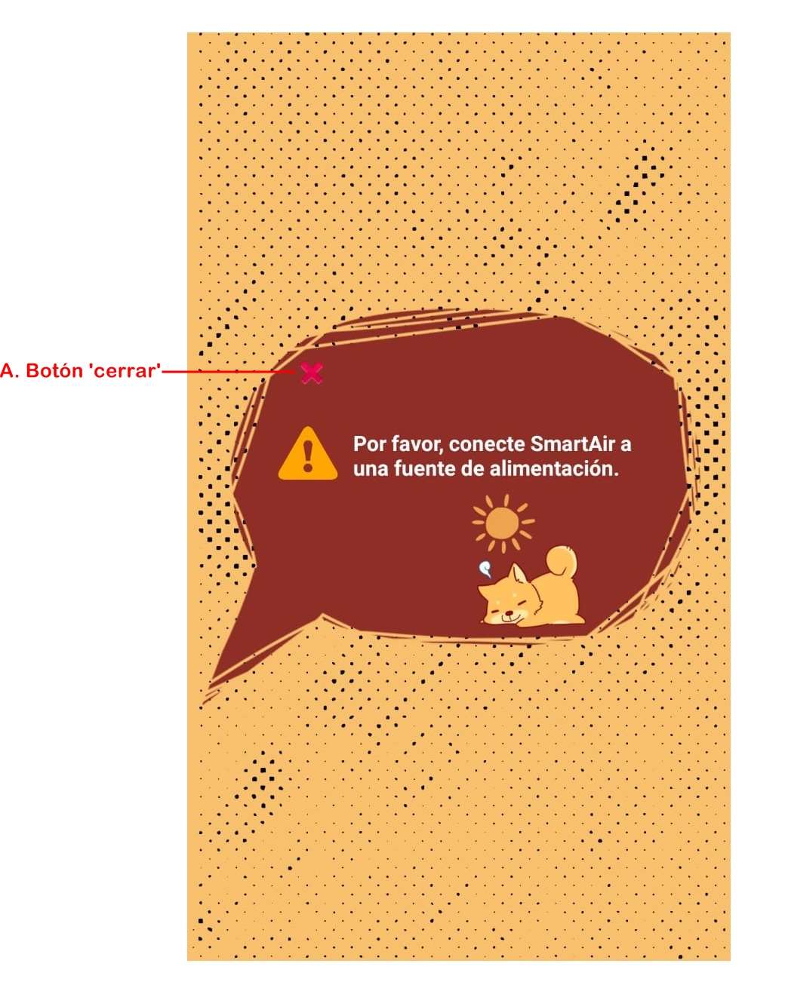
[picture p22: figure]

Página 32 de 34

- ErrorConexionCalorActivity:
A. Botón ‘cerrar’: Al seleccionar dicho botón cerraremos el mensaje de error que surge cuando existe una falla de conexión con SmartAir mientras se está en ‘modo calor’.

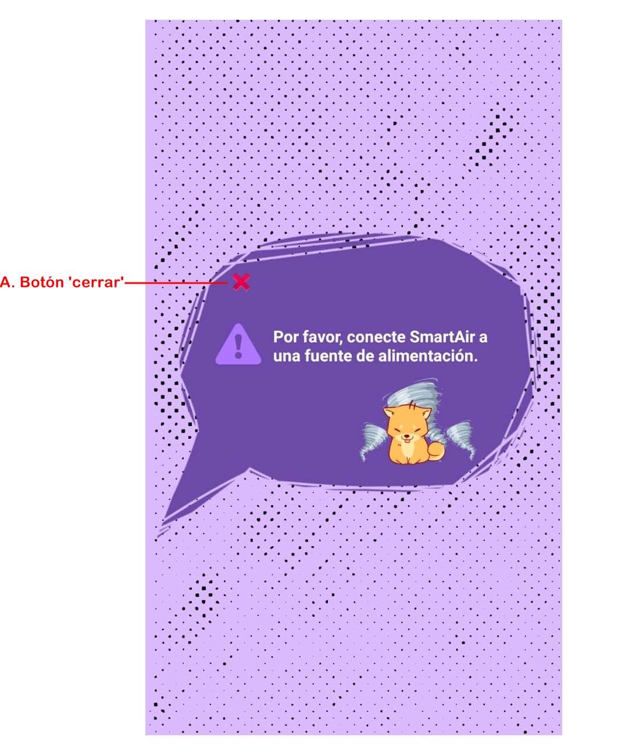
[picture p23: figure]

Página 33 de 34

-ErrorConexionVentilacionActivity:

A. Botón ‘cerrar’: Al seleccionar dicho botón cerraremos el mensaje de error que surge cuando existe una falla de conexión con SmartAir mientras se está en ‘modo ventilación’.

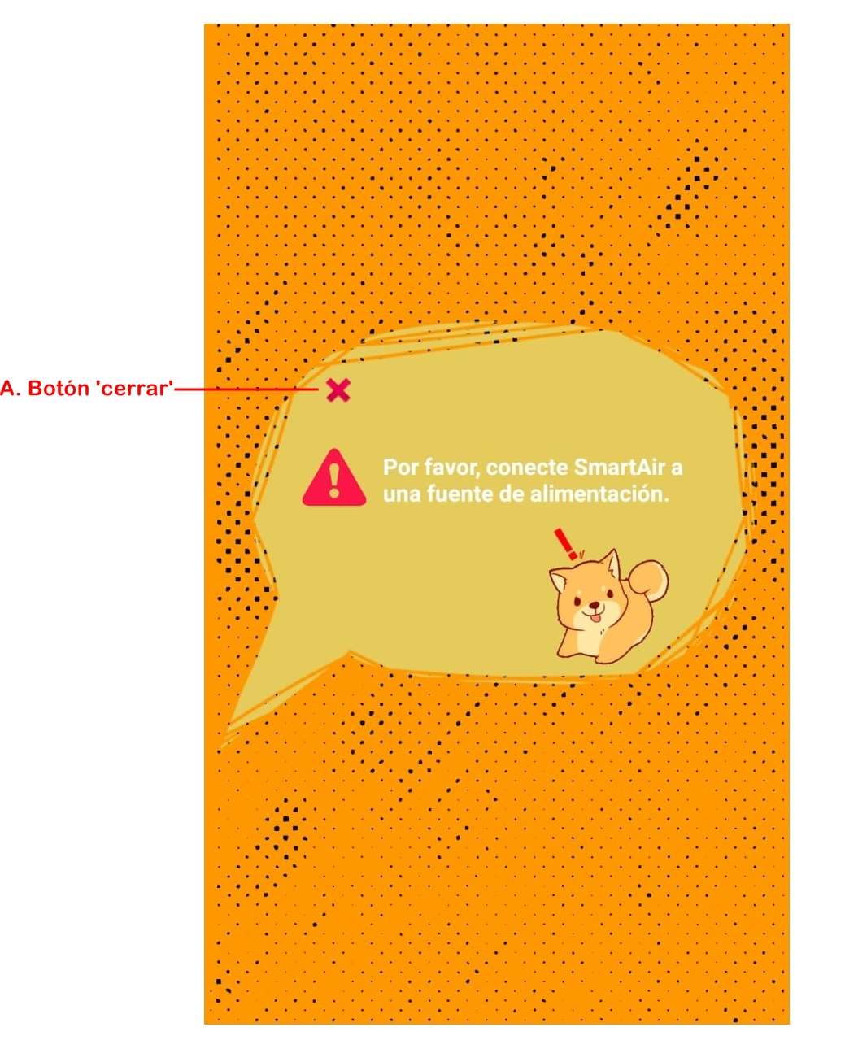
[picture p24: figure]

Página 34 de 34

-ErrorConexionAutomaticoActivity:

A. Botón ‘cerrar’: Al seleccionar dicho botón cerraremos el mensaje de error que surge cuando existe una falla de conexión con SmartAir mientras se está en ‘modo automático’.

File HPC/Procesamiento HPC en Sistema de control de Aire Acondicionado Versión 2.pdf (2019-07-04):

## Procesamiento HPC en Sistema de control de aire accondicionado

Bedetti Nicolas, Hoz Aylen, Torres Quimey

Universidad Nacional de La Matanza, Departamento de Ingeniería e Investigaciones Tecnológicas, Florencio Varela 1903 - San Justo, Argentina nbedetti@gmail.com; ailu.hoz28@gmail.com; quimey.torres@gmail.com

Resumen. El objetivo del presente documento de investigación es describir la opción por la cual se ha optado para manejar el gran volumen de datos entregados por diversos embebidos “SmartAir” dispersos en un edificio, teniendo en cuenta que el analisis de los datos se debe realizar de forma concurrente y la respuesta a los mismos debe ser en tiempo real como requisito. En base a este problema planteado se propone utilizar el paradigma OpenMP debido al soporte de paralelismo que este brinda.

Palabras claves: HPC, OpenMP, Servidor.

### 1 Introducción

La investigación desarrollada en este documento se aplica al sistema embebido “SmartAir”, sistema de control de aire accondicionado inteligente. Este embebido recibe información principalmente de los sensores de temperatura, uno interno para controlar la temperatura del aire que sale del dispositivo y uno externo que mide la temperatura ambiente, ademas de un sensor de inclinación que permite informar cuando el dispositivo es maltratado debido a que es portable; con esta información, según el modo elegido (frio, calor o automático (24°C)), los actuadores que lo conforman responderán a las peticiones de cada modo.
Se plantea el uso de diversos embebidos en un edificio aplicado a una industria o edificio en el cual el control de la temperatura ambiente es vital y deben realizarse mediciones constantes en tiempo real, ademas de procesar esta información para enviar reportes constantes de los usuarios del sistema que monitoreán y controlan los dispositivos desde una aplicación móvil. De tal forma, se presenta el problema del gran volumen de datos que debe procesar simultáneamente un servidor central en la nube encargado del control de todos los sensores y actuadores presentes en cada habitación del edifico, lo cual podrían generar que se sature y colapse.
Se propone procesar estos grandes volumenes de información de forma paralela, de tal forma se mejora el control por parte del servidor cloud y mejoran los tiempos de respuesta a las peticiones. Debido a los beneficios que otorga la implementación de la plataforma OpenMP debido a que no solo brinda paralelismo, sino que es portable, seguro y simple de implementar.
Se plantea la aplicación de una arquitectura FireBase [1] con un servidor cloud al cual se conectan los embebidos que envían constantemente las mediciones de los sensores para procesar la información para reportes y ser enviada a los dispositivos móviles que se encuentran suscriptos a estos, ademas el servidor deberá responder a las peticiones de los usuarios desde la aplicación, lo cual se asemeja a la utilización en sistemas SCADA (Supervisory Control And Data Acquisition) que utiliza técnicas de HPC con una gran computadora o servidor como esclavo en la red de los sensores y actuadores para la respuesta en tiempo real de peticiones y toma de mediciones [2].

### 2 Desarrollo

La presente investigación tiene como base la conexión de múltiples embebidos “SmartAir” aplicados al dominio de un edificio o industria. Actualmente, el embebido se trata de un aire accondicionado portatil con un sistema de control de la temperatura. Como se planteo en el inicio todos los embebidos serán conectados a un servidor central, por lo tanto, el análisis de la información recibida en tiempo real sería centralizada y controlada por un único servidor cloud, lo cual generaría, como ya se mencionó anteriormente, un retardo en los tiempos de respuesta de la aplicación para los usuarios de los dispositivos.
Para el desarrollo propuesto anteriormente es necesario contar con un sistema multiprocesador para la paralelización de los distintos procesos que van a responder a las peticiones de los usuarios. OpenMP permite inciar a partir de un código en serie y provee un enfoque incremental al paralelismo.
Para esta aplicación, se contará con un proceso inicial que empezara la ejecución, que se conoce como región serie, y luego se utilizarán distintos algoritmos que permitirán encolar a las peticiones de los usuarios, para luego ser distribuidas entre distintos hilos a través de directivas como fork/join mencionadas anteriormente, formando la región paralela [3]. También es necesario contar con una base de datos que pueda trabajar de forma paralela para almacenar la información obtenidad de los embebidos en logs para los reportes de tiempo real.


Fig 1: Xiaoxu Guan: Introduction to OpenMP (2016) pag 6. [3]

3 Explicación del algoritmo.

Cada embebido disperso en el edificio cuenta con dos sensores de temperatura (uno interno y otro externo) y un sensor de inclinación que permite apagar el dispositivo para que no se dañe al ser transportado durante su funcionamiento (además de brindar una alarma sonora con un buzzer), por otro lado, se recibe la velocidad a la cual funcionan los ventiladores que envían el aire hacia el exterior del dispositivo. Todos estos datos de entrada serán enviados por el embebido en tiempo real al servidor cloud y serán utilizados para el control de la temperatura ambiente de la habitación en la cual se encuentra el dispositivo según las preferencias del usuario que lo controla, teniendo encuentra la seguridad de los componentes internos del mismo.

El servidor central recibirá estos datos generando e informará a los usuarios en tiempo real el cambio en las mediciones identificando los embebidos, los valores obtenidos de los sensores, el modo en el que se encuentra y fecha y hora, lo cual también se almacenará en un log. El usuario de la aplicación podrá tener un análisis o reporte en tiempo real del maltrato que reciben los equipos, cuanto tiempo son utilizados, la energía que gastan (según el tiempo que están activos) y cuan eficientes son en enfriar o calentar la habitación en la que se encuentran.

Como se comentó en un principio, se utilizará una base de datos central situada en el servidor cloud (arquitectura FireBase) para el log de acciones realizadas común a todos los embebidos y todos los hilos accederán de forma concurrente, por lo tanto, se implementarán regiones críticas para la escritura de los registros, protegiendo la integridad de la información [4].

Se decidió utilizar un servidor cloud con un procesador de ocho núcleos, por lo que se utilizarán ocho hilos y se implementarán las librerías de OpenMP (#include <omp.h>) para la implementación de concurrencia [5].


### 4 Pruebas que pueden realizarse

En primer lugar, se puede realizar un prueba que compare el tiempo de respuesta utilizando OpenMP tomando las mediciones de un solo embebido colocado en una habitación y luego compararla probando en simultáneo todos los embebidos colocados en todas las habitaciones realizando una prueba de exigencia máxima, verificando que el sistema responda a las peticiones de tiempo real en los tiempos de respuesta esperados.
Por último, se puede realizar una prueba que compare el tiempo de respuesta utilizando OpenMP y sin utilizarlo al utilizar al menos 20 embebidos de forma simultánea.Como resultado de esta prueba veríamos los beneficios que otorga el uso de OpenMP en cuanto a paralelismo y tiempo de respuesta.

### 5 Conclusiones

Durante el desarrollo de este trabajo se propuso expandir el domino de los embebidos “SmartAir” para controlar varios dispositivos en un edificio utilizando OpenMP, lo cual nos permitió paralelizar el procesamiento de la información y guardarla de forma segura en una base de datos.
La investigación realizada nos permitió aprender a resolver un problema serial de tiempo real de forma paralela.
Por último, a pesar de que la paralelización hizo que los tiempos de respuesta se redujeran considerablemente, la utilización de un servidor cloud puede generar problemas en caso de fallas en el servidor, por lo tanto, en futuras mejoras se implementaría el concepto de computación distribuida en diversos servidores cloud con el uso de MPI.
En conclusión, OpenMP resulto ser la mejor elección para el desarrollo de este trabajo debido a que como se describió en un principio brinda paralelismo, es portable, seguro y simple de implementar.

### 6 Referencias

1. Caldera Carlos, Lopez Jesús, Olivas Héctor y Gallegos José: Diseño de sistema de control automatizado con sistemas embebidos, aplicaciones móviles y el internet de las cosas (2017)
http://www.ecorfan.org/bolivia/researchjournals/Tecnologia_e_innovacion/vol4num11/Revista_de_Tecnologia_e_Innovacion_V4_N11_6.pdf

### 2. Birman, Kenneth P., Lakshmi Ganesh, and Robbert Van Renesse: Running smart grid

control | software | on | cloud | computing | architectures. (2011)
http://citeseerx.ist.psu.edu/viewdoc/download?doi=10.1.1.229.4216&rep=rep1&type=pdf

### 3. Xiaoxu Guan: Introduction to OpenMP (2016) http://www.hpc.lsu.edu/training/weekly-

materials/2016-Spring/OpenMP-06Apr2016.pdf

### 4. Adam Bird, David Long, Geoff Dobson: Implementing Shared Memory Parallelism in

MCBEND | (2017) | https://www.epj-
conferences.org/articles/epjconf/pdf/2017/22/epjconf_icrs2017_07042.pdf
5. Chapman | Barbara: | How | OpenMP | is | Compiled | (2015)
http://www.compunity.org/events/pastevents/parco07/tut-compilerrev-chapman_new.pdf

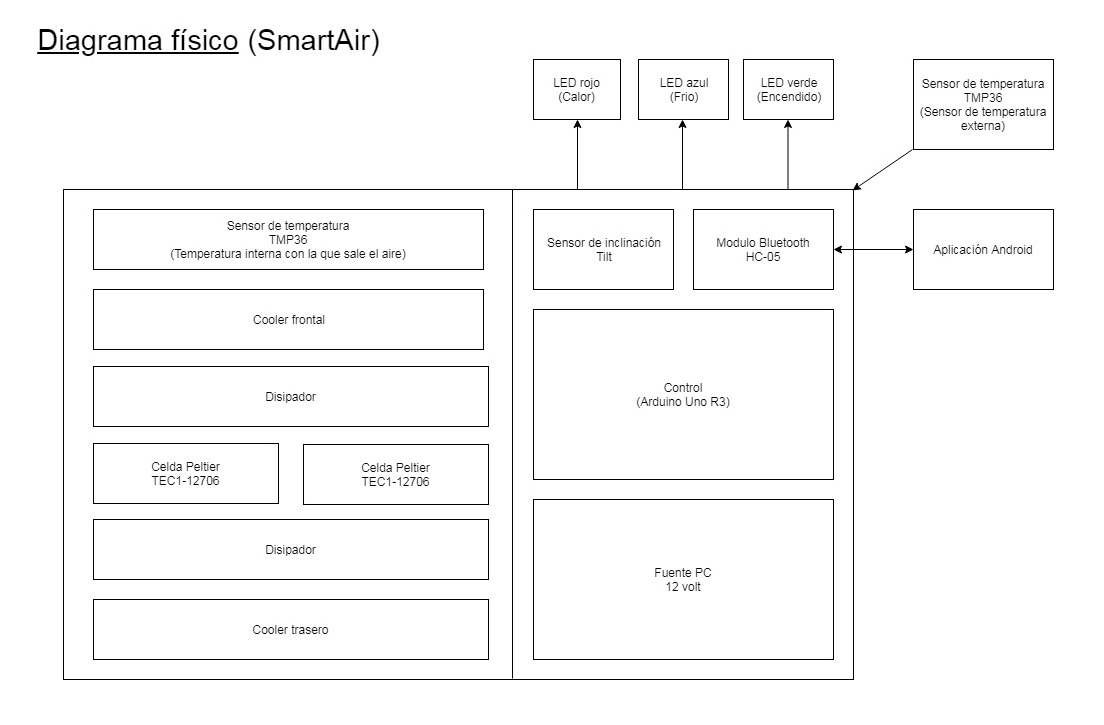
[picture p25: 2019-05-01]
Sistema-Embebido/Diagrama de bloques/Diagrama físico - SmartAir.jpg

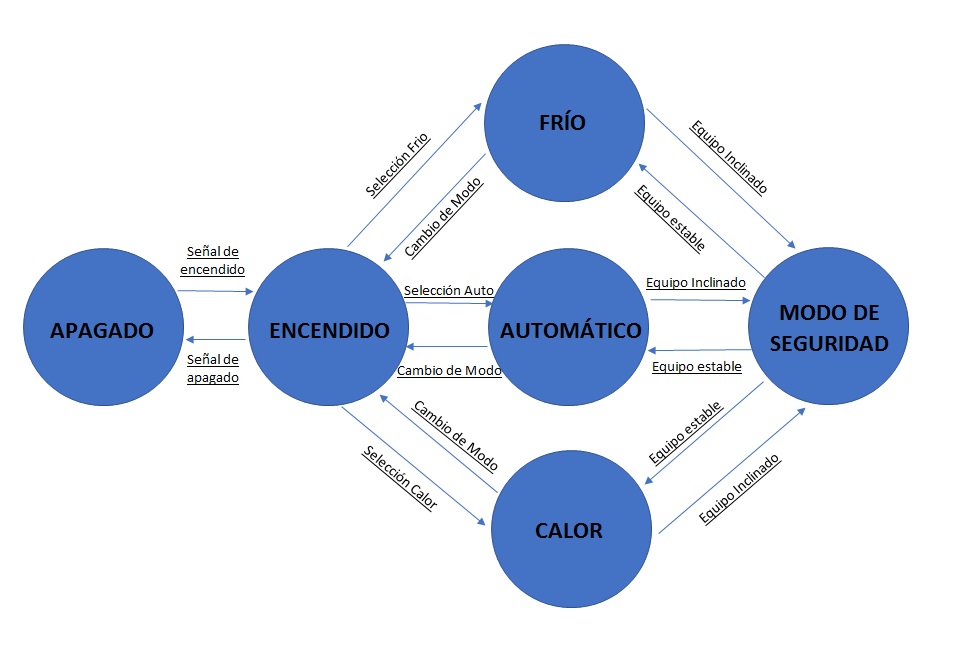
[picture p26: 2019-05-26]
Sistema-Embebido/Diagrama de bloques/Diagrama de estados - SmartAir.jpg

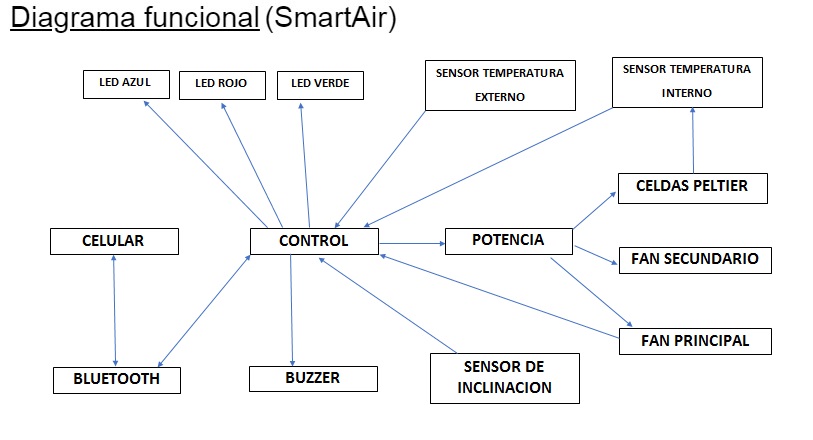
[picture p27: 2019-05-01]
Sistema-Embebido/Diagrama de bloques/Diagrama funcional - SmartAir.jpg

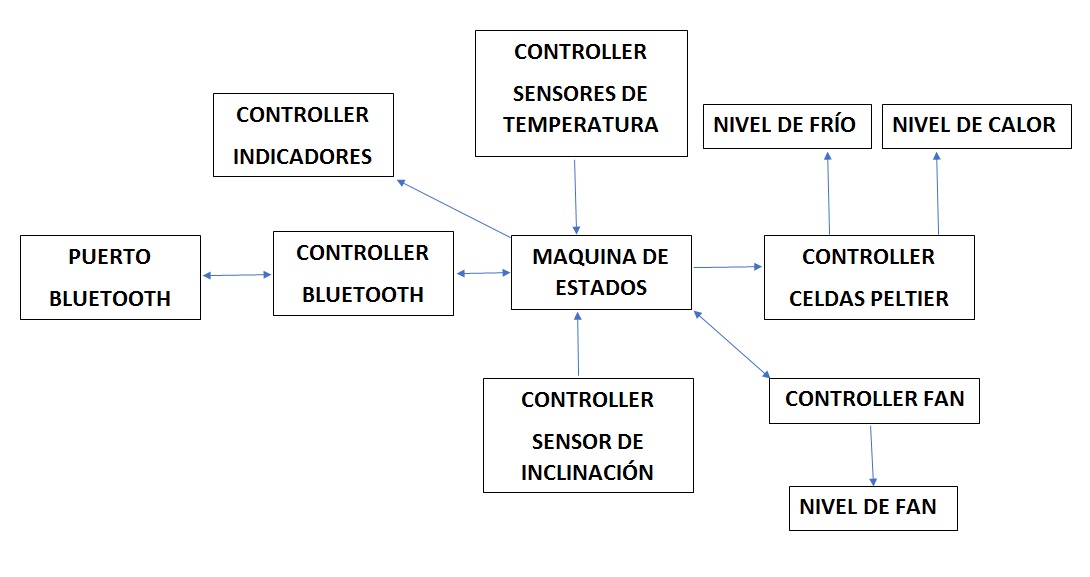
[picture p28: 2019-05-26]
Sistema-Embebido/Diagrama de bloques/Diagrama de software - SmartAir.jpg

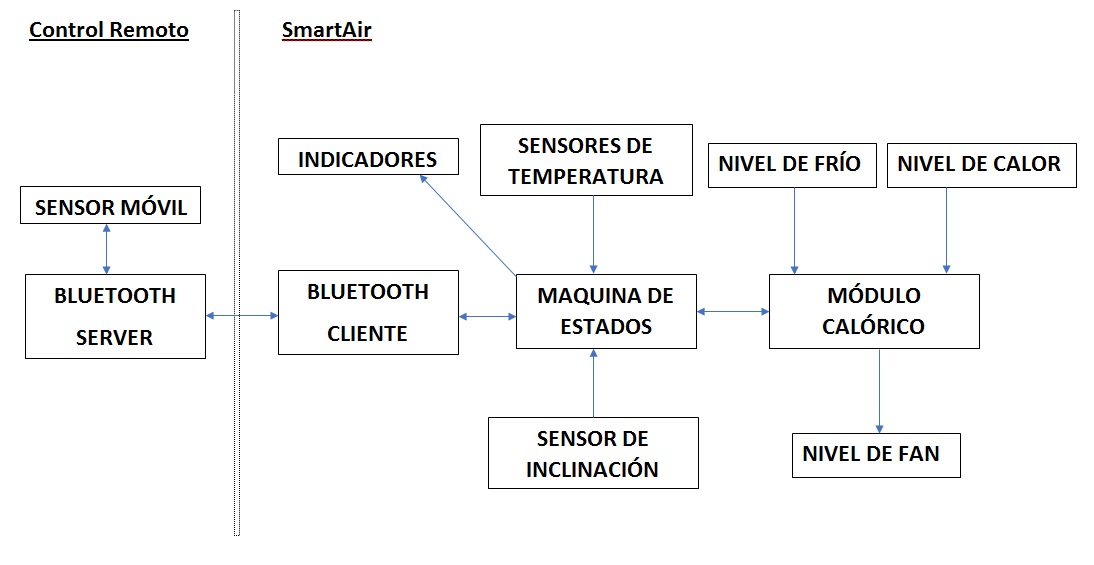
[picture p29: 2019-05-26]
Sistema-Embebido/Diagrama de bloques/Diagrama lógico - SmartAir.jpg

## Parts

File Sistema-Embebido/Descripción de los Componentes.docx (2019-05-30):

# Descripción de los Componentes

## Arduino UNO:

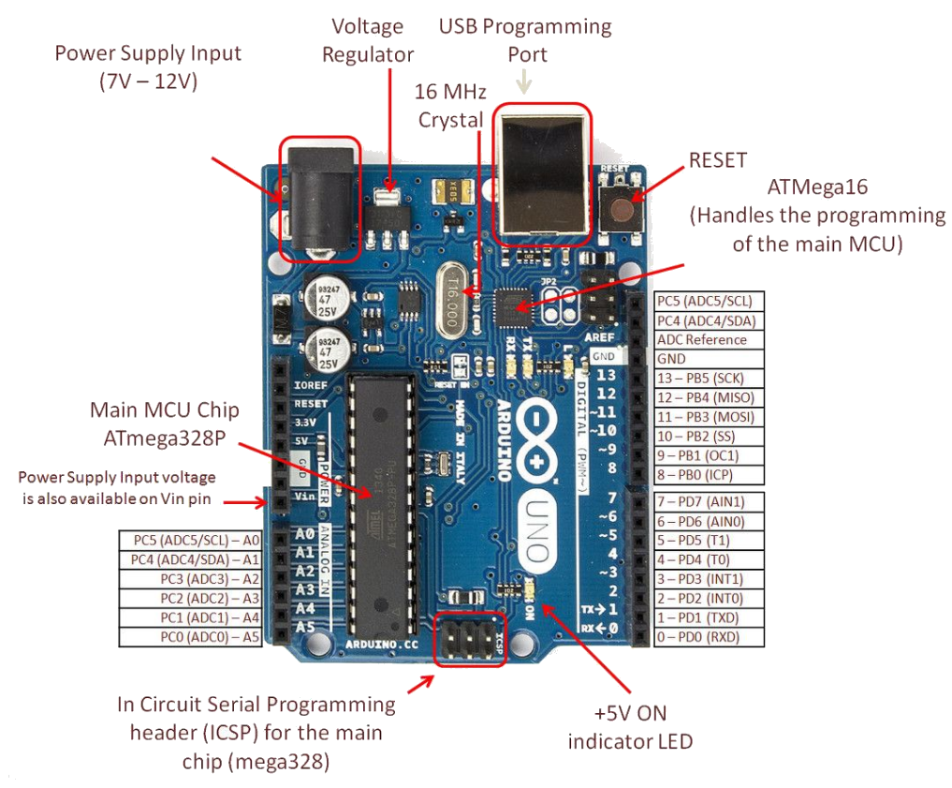
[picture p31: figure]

Arduino es una plataforma de prototipos electrónica de código abierto (open-source) basada en hardware y software flexibles y fáciles de usar. Arduino puede sentir el entorno mediante la recepción de entradas desde una variedad de sensores y puede afectar a su alrededor mediante el control de luces, motores y otros artefactos. El microcontrolador de la placa se programa usando el Arduino Programming Language (basado en Wiring).

La mayor parte de los Arduinos funcionan a 5V, como es el caso del Arduino Uno. Todos tienen un regulador de tensión, que básicamente es un componente que convierte el voltaje que con el que alimentamos la placa (lo recomendado es entre 7 y 12V) a 5V, desechando lo restante.

Este regulador necesita un voltaje mínimo para para proporcionar 5V que está entorno 6.5-7V, pero todo lo que esté por encima de ese valor se desperdicia.

## Módulo Bluetooth HC-05

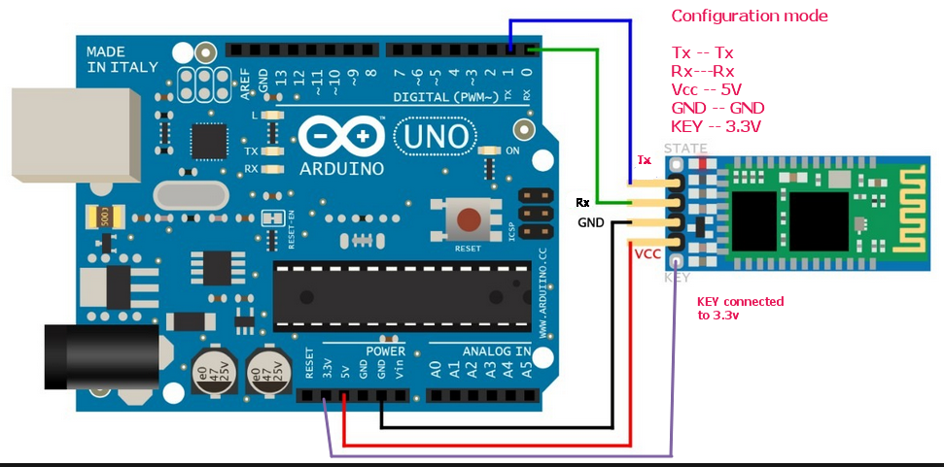
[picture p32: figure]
Resultado de imagen para hc 05

Estos módulos vienen maestro y esclavo en una misma placa y vía comandos AT se configura cuál de los dos modos queremos usar. Por defecto viene en modo Esclavo.

El chip en si trabaja en 3.3 V, pero viene soldado sobre una placa que adapta todos sus pines para poder usarlo en 5V y así sea 100% compatible con Arduino.

La velocidad por defecto es de 9600 baudios.

Tiene un alcance de 18 metros.

Modulo bluetooth hc-05 como esclavo: Cuando está configurado de esta forma, se comporta similar a un HC-06, espera que un dispositivo bluetooth maestro se conecte a este, generalmente se utiliza cuando se necesita comunicarse con una PC o Celular, pues estos se comportan como dispositivos maestros.

Modulo bluetooth hc-05 como Maestro: En este modo, EL HC-05 es el que inicia la conexión. Un dispositivo maestro solo se puede conectarse con un dispositivo esclavo. Generalmente se utiliza este modo para comunicarse entre módulos bluetooth. Es necesario antes especificar con qué dispositivo se tiene que comunicar. Mediante el pin TX, Arduino enviará datos, y mediante el RX, recibirá datos.

## Sensor de Temperatura TMP-36

El sensor de temperatura TMP36 es un sensor analógico que permite realizar medidas de temperatura bastante precisas.

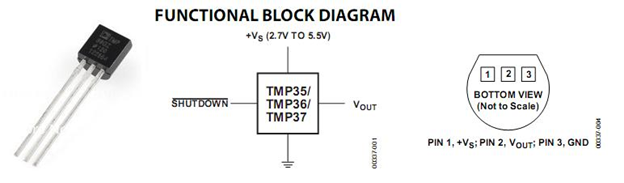
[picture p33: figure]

El sensor empleado es de tipo TO-92 (encapsulado como el DS18B20 o el de algunos transistores). Además, se caracteriza por ser un sensor que es muy empleado para realizar medidas de temperatura y es muy sencillo de emplear (no hacen falta librerías para su uso). Es un sensor que se puede alimentar entre un rango de voltaje que va desde los 2.7V hasta los 5.5V, viene calibrado directamente en grados centígrados (ºC), presenta un factor de escala lineal de 10 mV/ºC (esto es la relación entre el cambio en la señal de salida y el cambio en la señal de la medida, es decir, cada 10 mV aumenta 1 ºC). Las características generales son:

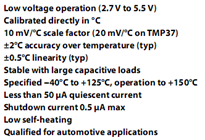
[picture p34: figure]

## Sensor de Inclinación

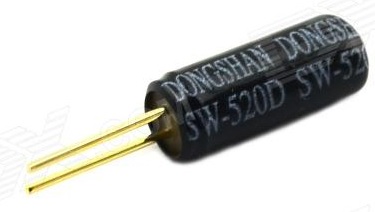
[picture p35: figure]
Tilt switch

Son sensores de unos pocos milímetros de longitud, que llevan en su interior una o dos pequeñas bolas conductoras, capaces de cerrar el circuito con los pines metálicos inferiores del cilindro.

Cuando hacen contacto permiten el paso de la corriente y cierran el contacto exactamente igual que si fueran un interruptor (Y de hecho se manejan igual) pero que a partir de un cierto Angulo de inclinación dejan de hacer contacto y abren el contacto.

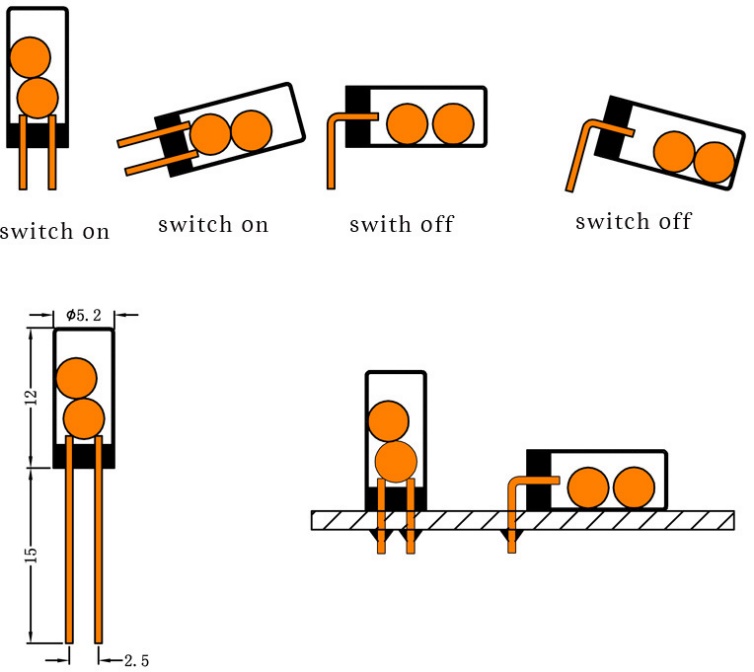
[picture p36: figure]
Sensor de inclinacion

## LED

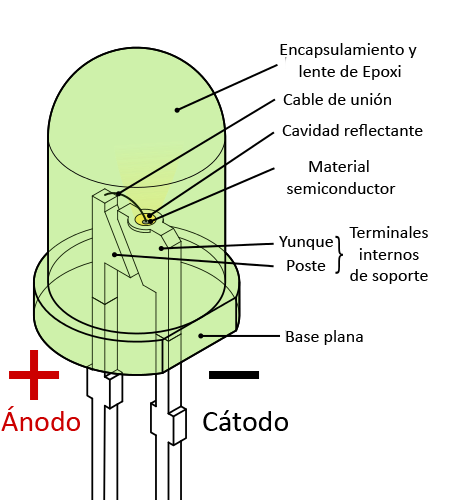
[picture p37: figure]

Un diodo emisor de luz o led (light-emitting diode) es una fuente de luz constituida por un material semiconductor dotado de dos terminales. Se trata de un diodo de unión p-n, que emite luz cuando está activado. Si se aplica una tensión adecuada a los terminales, los electrones se recombinan con los huecos en la región de la unión p-n del dispositivo, liberando energía en forma de fotones. Este efecto se denomina electroluminiscencia, y el color de la luz generada (que depende de la energía de los fotones emitidos) viene determinado por la anchura de la banda prohibida del semiconductor. Los ledes son normalmente pequeños (menos de 1 mm) y se les asocian algunas componentes ópticas para configurar un patrón de radiación.

## Buzzer

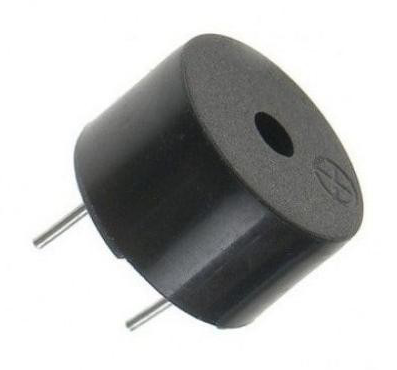
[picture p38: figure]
Resultado de imagen para buzzer pasivo

Es un transductor electroacústico que produce un sonido o zumbido continuo o intermitente de un mismo tono (generalmente agudo). Sirve como mecanismo de señalización o aviso y se utiliza en múltiples sistemas, como en automóviles o en electrodomésticos, incluidos los despertadores.

Inicialmente este dispositivo estaba basado en un sistema electromecánico que era similar a una campana eléctrica, pero sin el badajo metálico, el cual imitaba el sonido de una campana.

Su construcción consta de dos elementos, un electroimán o disco piezoeléctrico y una lámina metálica de acero. El buzzer puede ser conectado a circuitos integrados especiales para así lograr distintos tonos.

Cuando se acciona, la corriente pasa por la bobina del electroimán y produce un campo magnético variable que hace vibrar la lámina de acero sobre la armadura, o bien, la corriente pasa por el disco piezoeléctrico haciéndolo entrar en resonancia eléctrica y produciendo ultrasonidos que son amplificados por la lámina de acero.

## Celda Peltier TEC1-12706

C:\Users\quimey.belen.torres\AppData\Local\Microsoft\Windows\INetCache\Content.MSO\1F2EE303.tmp

Especificaciones:

- Material cerámico
- Cable de 30cm
- Temperatura lado caliente: 50-57ºC
- Delta de temperatura: 66-75ºC
- Corriente máxima: 6.4A
- Voltaje nominal: 12V
- Voltaje máximo: 16.4V
- Potencia nominal: 72W
- Resistencia de la celda 1.98-2.30 Ohms

Se utiliza para enfriar o calentar un objeto, ideal para experimentos o controles de temperatura, si se utiliza por largos periodos de tiempo se recomienda utilizar un disipador en la zona caliente, además de recubrir la zona con pasta termina para una mejor termo conducción de los materiales. La celda se controla con 12V, pero puedes utilizarla con un rango de voltaje de los 3 a los 16V. Dado que la celda consume una cantidad considerable de corriente tienes que tomar en cuenta que tu fuente tenga la corriente necesaria, si no, no va a funcionar con su máxima eficiencia.

Una celda peltier contiene un arreglo de paletas de semiconductor de material Bismuto Telurio que se encuentran dopadas con un tipo de portador positivo o negativo. Los pares de portadores se configuran para estar conectados en serie eléctricamente y en paralelo térmicamente hablando. Cuando un voltaje de corriente directa se aplica al módulo, las cargas positivas y negativas de los portadores absorben energía de un sustrato y la transfiere al sustrato del lado opuesto. La superficie que absorbe la energía caliente se enfría y la superficie donde la energía calorífica se desprende, se calienta. Si se polariza la celda peltier al inverso, el proceso enfría la cara opuesta.

Cuando una celda peltier se polariza, la cara o lado fría absorbe "calor" y la cara que pierde energía emite calor. La diferencia entre ambas caras hará que al final la celda se caliente más de lo que se enfría. Por lo tanto, para montar una celda peltier se requiere tener un disipador. De preferencia este disipador debería de ser de Aluminio el cual es más eficiente para dispersar la temperatura extra. Cuando una celda peltier se encuentra montada a un radiador se tiene una unidad de enfriado.

efecto peltier

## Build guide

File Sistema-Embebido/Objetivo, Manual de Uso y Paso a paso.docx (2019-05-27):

# Smart Air

# Objetivo

Desarrollar un Sistema embebido (Smart Air) aplicando los conocimientos adquiridos durante el cuatrimestre. SmartAir es un aire inverter pequeño y transportable controlado desde una aplicación Android desde tu celular.

Se tendrá la posibilidad de controlar la temperatura interna, la temperatura externa, entre otras funciones más detalladas a continuación.

# Descripción general del sistema – Manual de Uso

Smart Air es un producto diseñado especialmente para poder ser utilizado en cualquier lugar donde puede enchufarse, es perfecto para refrescarse en un día de verano o para calentarse en un día frío de invierno, gracias a que es un aire inverter. Brinda la posibilidad de prender y apagar el aparato, entre otras funciones, a través de una aplicación Android utilizando Bluetooth.

El sistema embebido (SE) tomará la temperatura exterior de la habitación en la que es colocado y la temperatura interna por donde el aire (cálido o frío) es expulsado. De esta forma al seleccionar en la aplicación el modo elegido, sea frío, calor o automático (24°C). Se encenderán en el modo correcto las placas Peltier que tiene internamente para generar frío o calor según corresponda.

Además, se podrá elegir desde la aplicación con qué velocidad queremos que el aire sea expulsado en caso de requerir enfriar o calentar la habitación más rápido.

Para un mejor uso es recomendable que la parte trasera del dispositivo donde se elimina el aire se apunte al exterior, al igual que los aires convencionales.

El dispositivo también cuenta con un sensor de inclinación el cual permite, cuando el dispositivo está encendido y es transportado, que este se apague para no generar daños internos.

Por último, cuenta con un buzzer que indica cuando el dispositivo se enciende, apaga, cambia de temperatura, velocidad y modo, además de tres leds frontales que indican el estado del dispositivo:

- Al encender el dispositivo se prenderá el led verde.
- Al estar en “modo frío”, además de mantener el led verde de encendido, se prenderá el led azul.
- Al estar en “modo calor”, además de mantener el led verde de encendido, se prenderá el led rojo.
- Al estar en “modo automático”, además de mantener el led verde de encendido, se prenderán los led azul y rojo.
- Por último, el dispositivo cuando con un “modo seguro”, este se activa cuando el sensor de inclinación detecta que el dispositivo se encuentra en una posición que compromete su integridad, cuando esto sucede se apagarán los led azul y rojo (según corresponda), el buzzer producirá un pitido constante y se apagarán las placas Peltier al igual que los ventiladores internos.

En la siguiente imagen se puede apreciar el dispositivo y como debe ser conectado:

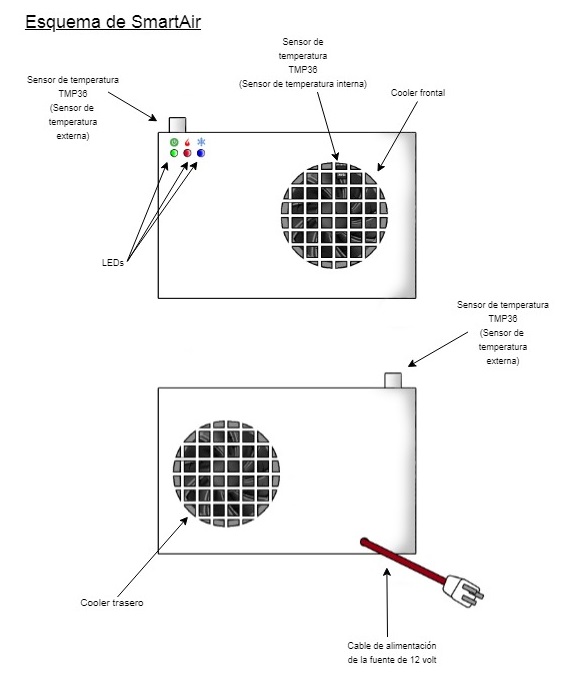
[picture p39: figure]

# Componentes

## Hardware:

- 1 Placa Arduino UNO SMD CH340.
- 1 Cable USB
- 2 Sensores de temperatura TMP-36.
- 1 Buzzer.
- 1 Sensor de inclinación.
- 1 Led Verde.
- 1 Led Rojo.
- 1 Led Azul.
- 2 Celdas Peltier TEC1-12706.
- Protoboard de 400 puntos.
- 2 Coolers con disipador de 8x8cm.
- 1 Fuente de computadora 12v.
- Cables macho-macho.
- Cables macho-hembra.
- Pines.
- Modulo Bluetooth HC-05.
- Resistencias 4k7.
- Transistores BC337.
- 2 Transistores IRF 540.
- 2 Transistores BC558.
- 2 Transistores BC548.
- Puente h (opcional para aire inverter).

# Implementación del Embebido

## Implementación Leds

Objetivo: Se colocan los leds para indicar los distintos estados por los que pasa el dispositivo:

- Encendido: Led verde encendida.
- Modo frío: Led Azul y Verde encendidos.
- Modo calos: Led Rojo y Verde encendidos.
- Modo automático: Led Azul, Rojo y Verde encendidos.

Señal: digital.

Estados: LOW (apagar) y HIGH (encender)

Pin Arduino:

- Pin 11: Led verde (encendido) configurado como salida.
- Pin 12: Led Azul (modo frío) configurado como salida.
- Pin 13: Led Rojo (modo calor) configurado como salida.

Circuito: Como se muestra en la imagen se conecta una resistencia de 4K7Ω al positivo del led y el otro extremo de la resistencia se conecta al pin del Arduino que controla el led. El extremo negativo del led se conecta al pin ground del Arduino.

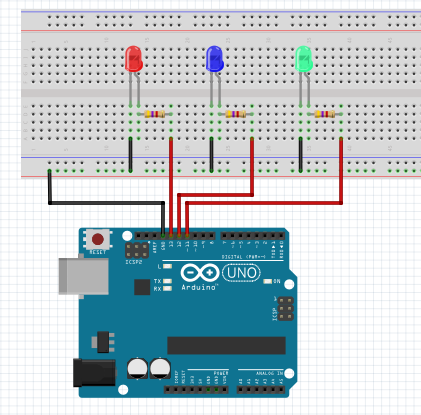
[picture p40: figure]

## Implementación de Sensor de inclinación

Objetivo: Se coloca un sensor de inclinación para proteger las partes delicadas del dispositivo cuando está encendido y es transportado. Cuando se detecta movimiento, las partes internar que generar frío o calor se apagan y se activa el buzzer para indicar que el dispositivo está en “modo seguridad”.

Señal: digital.

Estados: LOW (inclinado).

Pin Arduino: Pin 2 configurado como INPUT_PULLUP.

Circuito: Como se muestra en la imagen se conecta una resistencia de 4K7Ω al positivo del sensor de inclinación y el otro extremo de la resistencia se conecta al pin del Arduino que controla el led. El extremo negativo del sensor se conecta al pin ground del Arduino.

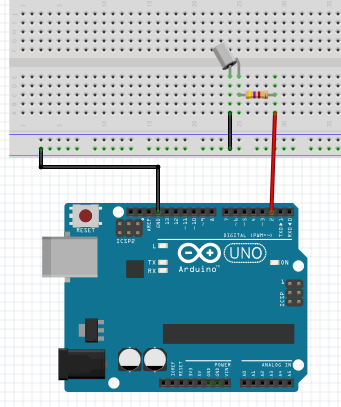
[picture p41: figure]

## Implementación de Buzzer

Objetivo: Se coloca un buzzer para indicar de forma sonora las acciones realizadas por el usuario. El buzzer sonará al encerder, cambiar de modo, subir o bajar temperatura y velocidad de los cooler. También indica el “modo seguridad” cuando se inclina el dispositivo sonando de forma constante hasta que el dispositivo vuelva a la posición correcta.

Señal: digital.

Estados: tone(buzzer,<tiempo>) , notone(buzzer).

Pin Arduino: Pin 8 configurado como salida.

Circuito: Como se muestra en la imagen se conecta el buzzer al pin del Arduino que lo controla de forma directa. El extremo negativo del buzzer se conecta al pin ground del Arduino.

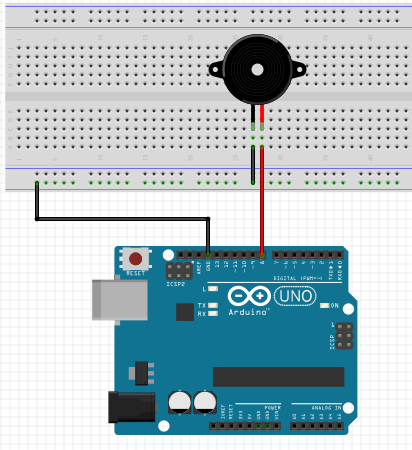
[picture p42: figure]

## Implementación de sensores de temperatura

Objetivo: Se colocan dos sensores de temperatura (uno interno al dispositivo y otro externo) para medir la temperatura y eventualmente controlarla con las celdas Peltier y los coolers.

Señal: analógica. Es un sensor que se puede alimentar entre un rango de voltaje que va desde los 2.7V hasta los 5.5V, viene calibrado directamente en grados centígrados (ºC), presenta un factor de escala lineal de 10 mV/ºC (esto es la relación entre el cambio en la señal de salida y el cambio en la señal de la medida, es decir, cada 10 mV aumenta 1 ºC).

Pin Arduino:

- Pin Analógico 0 (entrada): Sensor de temperatura TMP36 (temperatura interna)
- Pin Analógico 1 (entrada): Sensor de temperatura TMP36 (temperatura externa)

Circuito: Como se muestra en la imagen se conectan los conectores del medio de los sensores de temperatura a los pines analógicos que serán configurados como entradas, luego se conecta el conector izquierdo a 5V y el derecho al ground del Arduino.

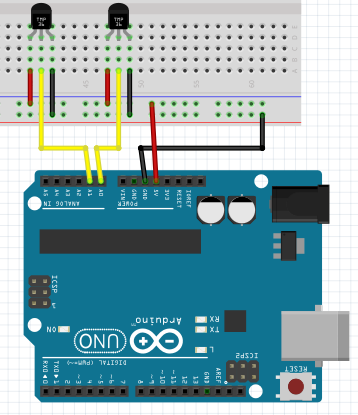
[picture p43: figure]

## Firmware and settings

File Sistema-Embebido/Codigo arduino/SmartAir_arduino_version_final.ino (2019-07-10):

#include <SoftwareSerial.h>
#define DIFERECIA_TEMPERATURA 1
#define TEMPERATURA_MAXIMA 26
#define TEMPERATURA_MINIMA 18
#define FAN_MAXIMO 4
#define  FAN_MINIMO 1
#define SUBIR 1
#define BAJAR 0
#define VEL_NULA 0
#define VEL_BAJA 64
#define VEL_MEDIA 128
#define VEL_MEDIA_ALTA 192
#define VEL_ALTA 255
#define MIN 0
#define MAX 12
#define NO_ESTADO -1
#define ERROR_FUNCTION -1

char SEPARADOR='|';
String INICIOINFO="info";
String FIN="fin";
bool _init = false;

/****PINES DIGITALES****/
int sensor_incl = 2; //digital
/*int led_blanco=7; //digital*/
int led_verde = 4; //digital
int buzzer = 3; //pwm
int led_azul = 12; //digital
int led_rojo = 13; //digital
int peltier_calor = 6;
int peltier_frio =7;
int fan = 5;
SoftwareSerial BT(10, 11);

/****PINES ANALOGICOS****/
int sensor_temp_interna= 0; //TMP-36
int sensor_temp_externa=1; //LM35
int temp_externa;
int temp_interna;
int temperatura_SmartAir=24;
int velocidad_fan=2;

int umbral_temp=18;
int dejar_sonar=0;
int buzzer_tone=0;
int lectura_incl;
int flag=0;
int inicio_tone;
int inicio_pausa=0;
bool pausa_buzzer=0;
int buzzer_noTone=0;
int inicio_soft;
int sonido_inicio;
bool inclinacion;

long tiempo_incl = 0;


enum estadoSmartAir
{
  INICIO=0,
  APAGADO,
  PRENDIDO,
};

enum estadoApagado
{
  INICIO_APAGADO=0,
  ESPERANDO_PRENDIDO,
};

enum estadoPrendido
{
  FRIO=0,
  CALOR,
  AUTOMATICO,
  MODOSEGURO,
  ESPERANDO_ORDEN,
  VENTILACION,
};

enum acciones
{
  PRENDER=0,
  APAGAR,
  CAMBIAR_ESTADO_FRIO,
  CAMBIAR_ESTADO_CALOR,
  CAMBIAR_ESTADO_VENTILACION,
  CAMBIAR_ESTADO_AUTOMATICO,
  FORZAR_MODO_SEGURO,
  FORZAR_SALIDA_MODO_SEGURO,
  SUBIR_FAN,
  BAJAR_FAN,
  SUBIR_TEMP,
  BAJAR_TEMP,
  ENVIAR_INFO
};

estadoSmartAir estadoSA;
estadoApagado estadoOFF=NO_ESTADO;
estadoPrendido estadoON=NO_ESTADO;
estadoPrendido estado_anterior_ON=NO_ESTADO;

void encenderPeltierFrio(){
  digitalWrite(peltier_calor,LOW);
  digitalWrite(peltier_frio,HIGH); 
}

void encenderPeltierCalor(){
  digitalWrite(peltier_calor,HIGH);
  digitalWrite(peltier_frio,LOW); 
}
void apagarPeltier(){
  digitalWrite(peltier_frio,LOW);
  digitalWrite(peltier_calor,LOW);

}

void encenderFan(){
  digitalWrite(fan, VEL_MEDIA_ALTA);
}

void apagarFan(){
  digitalWrite(fan,VEL_NULA);
}


/****FUNCION PARA SONAR BUZZER AL INICIO****/
void sonarBuzzerAlInicio(int tiempo_sonido)
{
  int aux=millis();
  if(buzzer_tone==0)
  {
    inicio_tone=millis();
    tone(buzzer,5000);
  }
  else
  {
    if(tiempo_sonido<aux-inicio_tone)
    {
      buzzer_tone=0;
      noTone(buzzer);
      sonido_inicio=0;
    }
  }
}

void enviarInfo(){
  String info="";
  info+=INICIOINFO;
  info+=SEPARADOR;
  info+=estadoSA;
  info+=SEPARADOR;
  info+=estadoON;
  info+=SEPARADOR;
  info+=temperatura_SmartAir;
  info+=SEPARADOR;
  info+=temp_externa;
  info+=SEPARADOR;
  info+=temp_interna;
  info+=SEPARADOR;
  info+=velocidad_fan;
  info+=SEPARADOR;
  info+=inclinacion;
  info+=SEPARADOR;
  info+=FIN;

  BT.println(info);
  
}

void procesarFan(bool accion){

  if(accion == SUBIR)
  {   
      if(velocidad_fan<FAN_MAXIMO){
        Serial.println("Subo FAN.");
          velocidad_fan++;
      }
  }else 
  {
      if(velocidad_fan>FAN_MINIMO){
        Serial.println("Bajo FAN.");
          velocidad_fan--;
      }
  }
  
  switch(velocidad_fan)
  {
    case 1:
    {
      digitalWrite(fan,VEL_BAJA);
      break;
    }
    case 2:
    {
      digitalWrite(fan, VEL_MEDIA);
      break;
    }
     case 3:
    {
      digitalWrite(fan, VEL_MEDIA_ALTA);
      break;
    }
    case 4:
    {
      digitalWrite(fan, VEL_ALTA);
      break;
    }
  }
}

void procesarTemperatura(bool accion){

   if(accion == SUBIR)
  {   
      if(temperatura_SmartAir<TEMPERATURA_MAXIMA){
          temperatura_SmartAir++;
          Serial.println("Subo TEMPERATURA.");
      }
  }else 
  {
      if(temperatura_SmartAir>TEMPERATURA_MINIMA){
          temperatura_SmartAir--;
          Serial.println("Bajo TEMPERATURA.");
      }
  }
  
}

/****FUNCION PARA PREGUNTAR SI HAY ORDEN DE BT****/
int leerOrdenBT()
{
  String aux;
  //Ver esta seccion donde debo asignarle a bluetooth_mando lo que envia el BT
   if (BT.available()){
        aux=BT.readString();
        BT.flush();
        if(aux){
               
          Serial.print(atoi(aux.c_str()));
          return atoi(aux.c_str());
        }
    
   }
      return ERROR_FUNCTION;
            
}

void procesarBT(int comando)
{ 
  if(comando<MIN || comando>MAX)
    return;

    switch(comando){
          
          case PRENDER:
          {
            if(estadoSA==PRENDIDO)
              return;
            estadoSA=PRENDIDO;
            estadoON = ESPERANDO_ORDEN;
           break;
          }
          
          case APAGAR:
          {
            if(estadoSA==APAGADO)
              return;
            estadoSA=APAGADO;
            estadoOFF = INICIO_APAGADO;
            estadoON = NO_ESTADO;
            estado_anterior_ON = NO_ESTADO;
            break;
          }
          case CAMBIAR_ESTADO_FRIO:
          { 
            
            if(estadoSA==APAGADO)
              return;
            estadoSA=PRENDIDO; 
            estadoON=FRIO;
            break;
          }
          
          case CAMBIAR_ESTADO_CALOR:
          {
            
            if(estadoSA==APAGADO)
              return;
            estadoSA=PRENDIDO; 
            estadoON=CALOR;
            break;
          }
          
          case CAMBIAR_ESTADO_VENTILACION:
          {
            
            if(estadoSA==APAGADO)
              return;
            estadoSA=PRENDIDO; 
            estadoON=VENTILACION;
            break;
          }
          
          case CAMBIAR_ESTADO_AUTOMATICO:
          {
            
            if(estadoSA==APAGADO)
              return;
            estadoSA=PRENDIDO; 
            estadoON=AUTOMATICO;
            break;
          }
          
          case FORZAR_MODO_SEGURO:
          {
            
            if(estadoSA==APAGADO)
              return;
            estadoSA=PRENDIDO; 
            estadoON=MODOSEGURO;
            break;
          }
          
          case FORZAR_SALIDA_MODO_SEGURO:
          {          
            
            if(estadoSA==APAGADO)
              return;  
            estadoSA=PRENDIDO; 
            estadoON=estado_anterior_ON;
            break;
          }
          
          case SUBIR_FAN:
          {
            
            if(estadoSA==APAGADO)
              return;
            procesarFan(SUBIR);
            break;
          }
          
          case BAJAR_FAN:
          {
            
            if(estadoSA==APAGADO)
              return;
            procesarFan(BAJAR);
            break;
          }
          
          case SUBIR_TEMP:
          {
            
            if(estadoSA==APAGADO)
              return;
            procesarTemperatura(SUBIR);
            break;
          }
          
          case BAJAR_TEMP:
          {
            
            if(estadoSA==APAGADO)
              return;
            procesarTemperatura(BAJAR);
            break;
          }

          case ENVIAR_INFO:
          //cada tres segundos
              enviarInfo();
            break;
    }

  
   
  
}

int chequearTemperaturaSA(){

  return temp_externa - temperatura_SmartAir ;
  
  
}

/****FUNCION PARA SONAR BUZZER EN MODO SEGURO****/
void sonarBuzzerModoSeguro(int tiempo_sonido, int tiempo_pausa)
{
  int aux;
  if(buzzer_tone==0 && buzzer_noTone==0)
  {
    //Serial.println("Empece a sonar");
    tone(buzzer,5000);
    inicio_tone=millis();
    buzzer_tone=1;
  }
  else
  {
    aux=millis();
    if(buzzer_tone==1 && tiempo_sonido<aux-inicio_tone && buzzer_noTone==0)
    {
      //Serial.println("Deje de sonar, empieza mi pausa");
      //int sonido=aux-inicio_tone;
      //Serial.println(sonido);
      noTone(buzzer);
      buzzer_noTone=1;
      inicio_pausa=millis();
      buzzer_tone=0;
    }
    else
    {
      if(buzzer_noTone==1 && buzzer_tone==0 && tiempo_pausa<aux-inicio_pausa)
      {
        
        //Serial.println("Termino mi pausa");
        //int pausita=aux-inicio_pausa;
        //Serial.println(pausita);
        buzzer_noTone=0;
      }
    }
  }
  
}

/****FUNCION DE DETECTAR INCLINACION****/
bool detectarInclinacion()
{
  return digitalRead(sensor_incl);
  //return 0;
}

/****FUNCION DE VERIFICAR IR A MODO SEGURO****/
void verificarIrAModoSeguro()
{
  if (detectarInclinacion())
    {
      if(estadoSA == PRENDIDO && estadoON != MODOSEGURO)
      {
         Serial.println("SmartAir inclinado.");
         inclinacion = 1;
         estado_anterior_ON = estadoON;
         estadoON = MODOSEGURO;
         digitalWrite(led_rojo,LOW);
         digitalWrite(led_azul,LOW);
         apagarPeltier();
         apagarFan();
      }
    }
}

/****FUNCION PARA LEER TEMPERATURA****/
float leerTemperatura(int sensor_pin){        
    int temp = analogRead(sensor_pin);
    float temperatura_actual;
    if(sensor_pin==0)
    {
      temperatura_actual = (5.0 /1024 * temp) * 100 -50 ;  
    }
    else
    {
      temperatura_actual = (5.0 /1024 * temp) * 100 ;
    }
    
    //Serial.println(temperatura) ; 
    //if (temperatura >= umbral_temp) 
    //Serial.println("Se alcanzo la temperatura") ;
    return temperatura_actual;
}

/****SETUP DEL SOFTWARE****/
void setup() {
  // put your setup code here, to run once:
  Serial.begin(115200);
  Serial.println("Init Setup");
  

  /*Pines*/
  //LEDs
  pinMode(led_rojo,OUTPUT);
  pinMode(led_azul,OUTPUT);
  pinMode(led_verde,OUTPUT);
  pinMode(peltier_calor,OUTPUT);
  pinMode(peltier_frio,OUTPUT);
  pinMode(fan,OUTPUT);
  //Buzzer
  pinMode(buzzer,OUTPUT);
  //Sensor de inclinacion
  pinMode(sensor_incl, INPUT_PULLUP);
  //Bluetooth
  //pinMode(8, OUTPUT);        // Al poner en HIGH forzaremos el modo AT
  pinMode(9, OUTPUT);        // cuando se alimente de aqui
  digitalWrite(9, HIGH);
  //digitalWrite (8, HIGH);    //Enciende el modulo
  BT.begin(9600); 

  

  sonido_inicio=0;
  estadoSA = INICIO; 
  inclinacion = 0;
 
}

/****LOOP****/
void loop() {
  // put your main code here, to run repeatedly:

    //Leer temperatura externa
    temp_externa = leerTemperatura(sensor_temp_externa);

    //Leer temperatura interna
    temp_interna = leerTemperatura(sensor_temp_interna);
  //Leer Bluetooth
    procesarBT(leerOrdenBT());

  /*Cosas que se harán siempre (a menos que se esté en MODO SEGURO y fin_sonido_inicio)*/
 
    
    if(estadoSA==PRENDIDO)
    {

      if(estadoON!=MODOSEGURO)
      {
         //Verificar si ir a modo seguro
          verificarIrAModoSeguro();
      }
    }
  
  switch(estadoSA)
  {
    case INICIO:
    {
      //Encendemos el led blanco (inicio de SmartAir, no encendido)
//      digitalWrite(led_blanco,HIGH);

      estadoSA = APAGADO;
      estadoOFF = INICIO_APAGADO;
      Serial.println("Inicio.");

      break;
    }

    case APAGADO:
    {   
        switch(estadoOFF)
        {

          case INICIO_APAGADO:
          {
              /*Apagar componentes*/
              Serial.println("Inicio Apagado.");
              digitalWrite(led_rojo,HIGH);
              digitalWrite(led_azul,LOW);
              digitalWrite(led_verde,LOW);
              apagarPeltier();
              apagarFan();
              estadoOFF = ESPERANDO_PRENDIDO;
              break;
          }

          case ESPERANDO_PRENDIDO:
          {
              //Encendido por medio de la app
              /*
              if(bluetooth_mando=PRENDIDO)
              { 
              */
              //Serial.println("Esperando_Prendido.");
                //digitalWrite(led_verde,HIGH);
                //digitalWrite(led_blanco,LOW);
                //sonido_inicio=1;
              /*
              }
              */

              
              break;
          }
        }
       
      
    }

    case PRENDIDO:
    {
       switch(estadoON){

          case ESPERANDO_ORDEN:
          { 
            Serial.println("Esperando_Orden.");
            digitalWrite(led_verde,HIGH);
            digitalWrite(led_rojo,LOW);
            //Hacemos sonar el buzzer de inicio
            if(sonido_inicio==1)
            {
               sonarBuzzerAlInicio(200);
            }
            break;
          }
          
          case MODOSEGURO:
          {   
              Serial.println("Modo Seguro.");
              if(detectarInclinacion())
              {
                noTone(buzzer);
                estadoSA = PRENDIDO;
                estadoON = estado_anterior_ON;
                estado_anterior_ON=MODOSEGURO;
                inclinacion = 0;
              }
              else
              {
                sonarBuzzerModoSeguro(200,3000);
              }
               break;            
          }

          case FRIO:
          {
            if(estadoON!=estado_anterior_ON)
            {
              estado_anterior_ON=estadoON;
              digitalWrite(led_rojo,LOW);
              digitalWrite(led_azul,HIGH);
              Serial.println("FRIO");
              encenderFan();
              
            }
             if(chequearTemperaturaSA()>1)
                  encenderPeltierFrio();
             else if(chequearTemperaturaSA()<ERROR_FUNCTION)
                  apagarPeltier();        

            
            //chequeo estado si ya lleggue a la temperatura indicado para apagar peltier
            //estadoON = CALOR;
            break;
          }

          case CALOR:
          {
            if(estadoON!=estado_anterior_ON)
            {
              estado_anterior_ON=estadoON;
              digitalWrite(led_rojo,HIGH);
              digitalWrite(led_azul,LOW);
              Serial.println("CALOR"); 
              encenderFan();
            }
             if(chequearTemperaturaSA()<ERROR_FUNCTION)
                  encenderPeltierCalor();
             else if(chequearTemperaturaSA()>1)
                  apagarPeltier();
            //chequeo estado si ya lleggue a la temperatura indicado para apagar peltier
            break;
          }

          
          case AUTOMATICO:
          {
            
            if(estadoON!=estado_anterior_ON)
            {
              estado_anterior_ON=estadoON;
              Serial.println("AUTOMATICO");
              digitalWrite(led_rojo,HIGH);
              digitalWrite(led_azul,HIGH);
              temperatura_SmartAir=24;
              encenderFan();
             
            }
             if(chequearTemperaturaSA()>1)
                  encenderPeltierFrio();
                else if(chequearTemperaturaSA()<ERROR_FUNCTION)
                  encenderPeltierCalor();
                  else 
                    apagarPeltier();
            

            break;
          }

           case VENTILACION:
          {
            
            if(estadoON!=estado_anterior_ON)
            {
              estado_anterior_ON=estadoON;
              Serial.println("VENTILACION");
              digitalWrite(led_rojo,LOW);
              digitalWrite(led_azul,LOW);
              apagarPeltier();
              encenderFan();
            }

            break;
          }

          
       }
      
    }
  }



}

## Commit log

2019-04-17 Create Materiales
2019-05-27 Add files via upload
    Se agrega en un mismo documento el objetivo, el manual de uso, la lista de materiales y el paso a paso de las conexiones realizadas hasta el momento
2019-06-09 Add files via upload
    Circuito
2019-06-09 Add files via upload
    Circuito en Fritzing
    [Circuito completo.fzz]
2019-07-10 Add files via upload
    Entrega de Informe Final
